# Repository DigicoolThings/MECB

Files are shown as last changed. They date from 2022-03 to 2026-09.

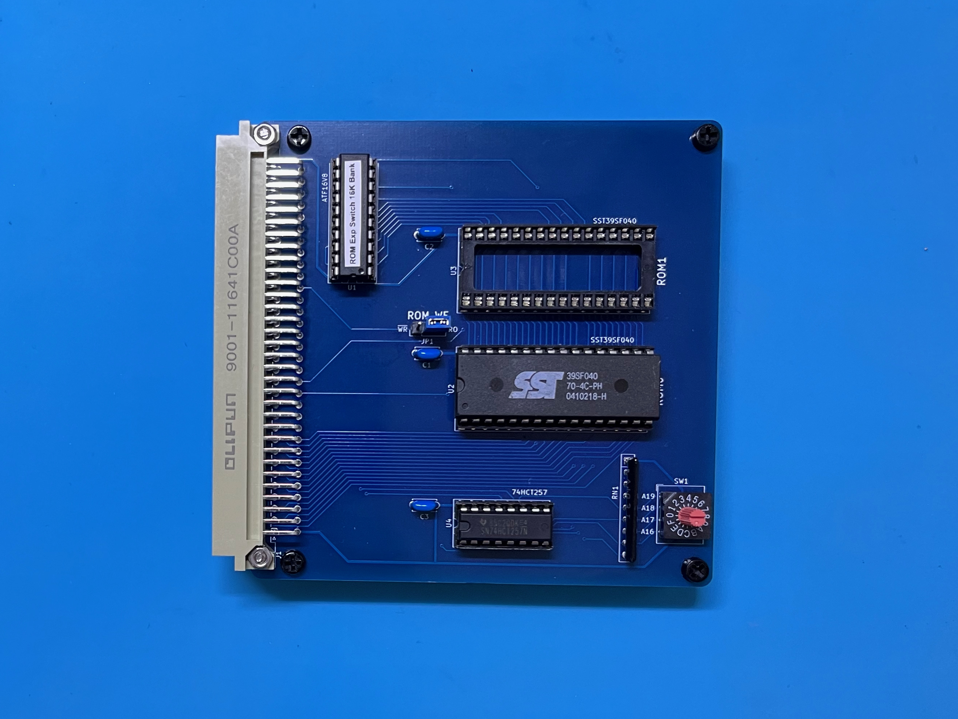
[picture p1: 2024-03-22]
MECB_1MB_ROM_Expansion/MECB_1MB_ROM_Expansion_Assembled.jpeg

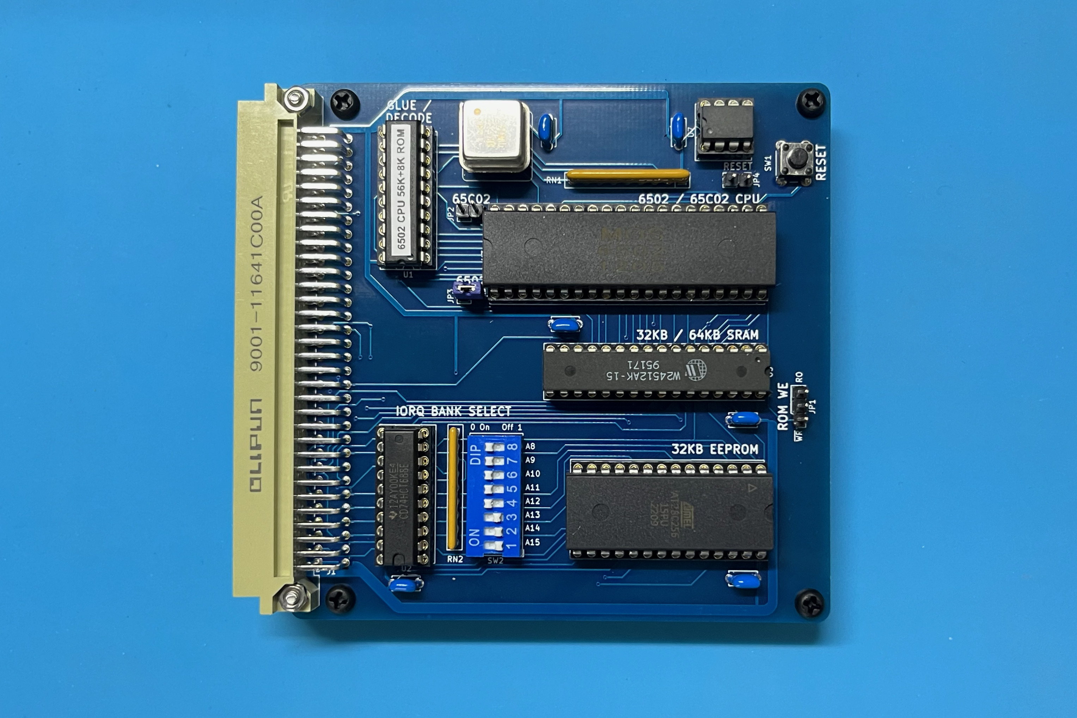
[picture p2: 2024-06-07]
MECB_6502_CPU/MECB_6502_CPU_Assembled_v1.0.jpeg

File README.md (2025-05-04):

# Minimalist Europe Card Bus (MECB)

Europe Card Bus (ECB) is a Retro CPU Bus standard from the late 1970’s / early 1980’s.

The “Minimalist Europe Card Bus” (MECB), as I call it, is a Retro 8-bit CPU Bus based PCB design standard that I decided to define & document. The purpose of which is to provide a modular platform for me to re-experience the fun of experimenting with the different 8-bit CPU’s, and the various video and peripheral devices, that I grew up with in the late 1970’s and early 1980’s.

My goal is that of a robust and modular design platform which would allow me to create interchangeable boards, based on time proven reliable bus connectors and modern low-cost prototype PCB manufacturing.

i.e. A robust, flexible, and low cost way for me to re-create some of the early microprocessor circuits, that I’d originally built using Wire-Wrap methods back in the day.

As evident from the name, the Bus itself is based on a Minimalist implementation of the original Europe Card Bus (ECB) standard.

The included 'MECB_Template_16V8' and 'MECB_Template_22V10' folders contains KiCAD v9 Templates to enable fast-tracking new MECB board designs. 
This templates also include the standardised PLD (either 16V8 or 22V10), for Address Decoding, and is as illustrated in the Standardised Board Mechanical Specifications diagram below.

To utilise either Template, simply copy the entire Template folder and contents into your KiCAD v9 'KICAD_USER_TEMPLATE_DIR' path folder (as defined under: Preferences -> Configure Paths...).

More information on the Minimalist Europe Card Bus (MECB) can be found here: https://digicoolthings.com/minimalist-europe-card-bus-mecb

## MECB Board Mechanical (MECB_BoardMechanical.pdf)
MECB_BoardMechanical

## MECB Bus Pinout (MECB_Bus_Pinout.png)
MECB_Bus_Pinout

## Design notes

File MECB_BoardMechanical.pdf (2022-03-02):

# Minimalist Europe Card Bus (MECB)

## Standardised Board - Mechanical Specifications

### Design Parameters

- Satisfy the 100mm square maximum board size, for low-cost prototype PCB manufacturing.
- Utilise the lower cost 64-pin (Row A&C) DIN 41612 type C connectors, for cost saving.
- Ensure the DIN 41612 connector(s) can be easily centred across the board width, grid aligned.
- Provide two standardised corner holes, on the edge opposing the right-angle DIN connector, to allow for attachment of card handles (to ease board insertion & extraction), or for board mounting – refer next point.
- Provide an additional two standardised corner mounting holes on the edge with the right-angle DIN connector, to provide a full set of four corner holes (to allow for stand-alone board mounting).
- Standardise PCB corner rounding, for sharp corner removal consistency across all boards & visual tidiness.

### Design Notes

1. PCB layout is designed utilising 0.127mm (5.0 mils) grid setting.
2. Board size is 99.822mm, which represents the greatest even multiple of 0.127mm (i.e. multiple of 0.254mm -10.0 mils), that will fit within the desired maximum 100mm board dimension.
3. Standard M3 sized mounting holes were chosen. An additional two mid-edge located mounting holes are specified for the Backplane board only (to provide additional mechanical support).
4. For reference, DIN 41612 connectors can utilise standard M2.5 mounting bolts (8mm length for the straight connectors, 10mm length for right angle connectors).
5. Implemented as a KiCAD Template, to assist with simplifying the creation of each new MECB board design.

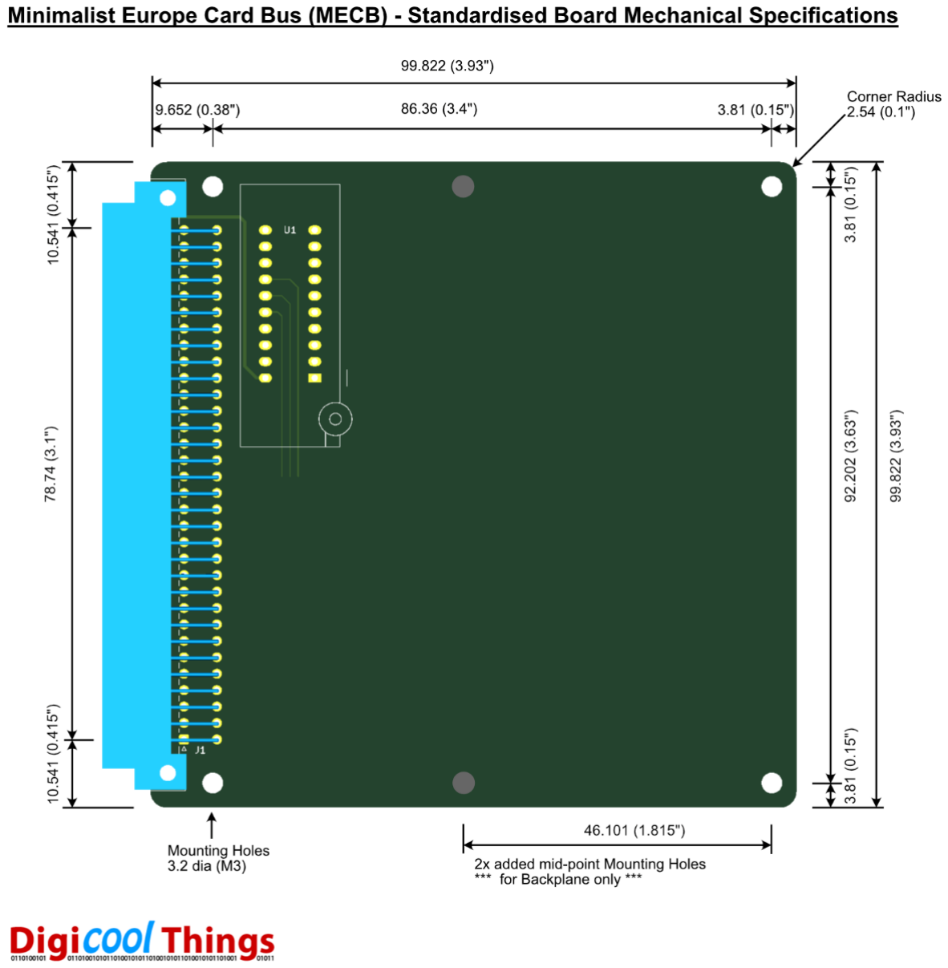
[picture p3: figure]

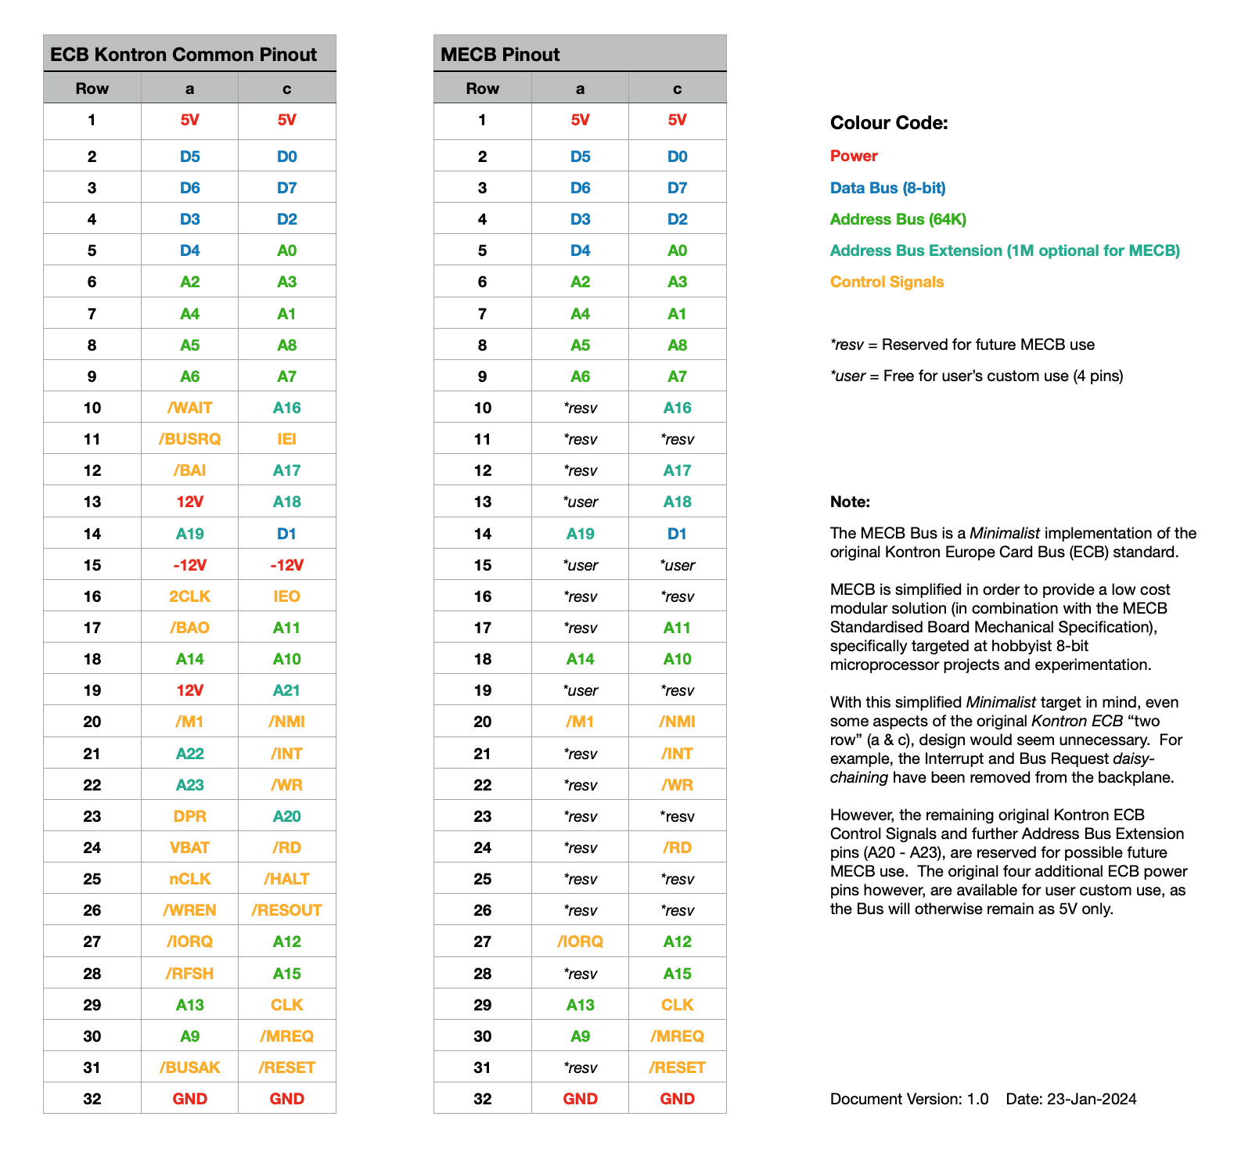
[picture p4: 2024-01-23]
MECB_Bus_Pinout.png

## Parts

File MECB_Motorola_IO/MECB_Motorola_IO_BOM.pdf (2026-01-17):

Item | Qty | Source
MECB Motorola I/O Card PCB | 1
DIN41612 Male R/A 364 Connector (J1) | 1 | Hardware Pack
M2.5 Bolt 10mm Thread Length | 2 | Hardware Pack
M2.5 Nut | 2 | Hardware Pack
12mm Nylon PCB Spacer | 4 | Hardware Pack
6mm Nylon Bolt | 8 | Hardware Pack
2 pin PCB Header (J2) | 1 | Hardware Pack
3 pin PCB Header (J7) | 1 | Hardware Pack
2 pin Jumper Cap | 1 | Hardware Pack
6 pin PCB Header Right-Angle (J6) | 1 | Hardware Pack
IDC Header 2x6 pin Straight (J4) | 1 | Hardware Pack
IDC Header 2x12 pin Right-Angle (J5) | 1 | Hardware Pack
3.5mm Phone Connector Audio Jack PCB Mount (J3) | 1 | Hardware Pack
4-way DIP Switch DIP8 (SW1) | 1 | Hardware Pack
ATF16V8 PLD DIP20 (U1) | 1 | Programmed ATF16V8 PLD Pack
Crystal Oscillator 4.9152Mhz DIP8 (X1) | 1 | Discrete Components Pack
0.1µf Capacitor 5mm (C1,C2,C3,C4,C5,C6) | 6 | Discrete Components Pack
47µf Radial Capacitor (C7) | 1 | Discrete Components Pack
3K3 Resistor 5.08mm (R1,R2) | 2 | Discrete Components Pack
VN10KN or 2N7000 N-Channel MOSFET TO92 (Q1) | 1 | Semiconductor Pack
74HCT393 Dual 4-bit binary ripple counter DIP14 (U2) | 1 | Semiconductor Pack
MC6850, MC68A50 or MC68B50 ACIA DIP24 (U3) | 1 | Semiconductor Pack
MC6840, MC68A40 or MC68B40 PTM DIP28 (U4) | 1 | Semiconductor Pack
SN76489AN Sound Generator DIP16 (U5) | 1 | Semiconductor Pack
MC6821, MC68A21 or MC68B21 PIA DIP40 (U6) | 1 | Semiconductor Pack
DIP40 IC Socket (for U6) | 1 | IC Socket Pack
DIP28 IC Socket (for U4) | 1 | IC Socket Pack
DIP24 IC Socket (for U3) | 1 | IC Socket Pack
DIP16 IC Socket (for U5) | 1 | IC Socket Pack
DIP14 IC Socket (for U2) | 1 | IC Socket Pack
DIP8 IC Socket (for X1) | 1 | IC Socket Pack

### MECB Motorola I/O - BOM

1

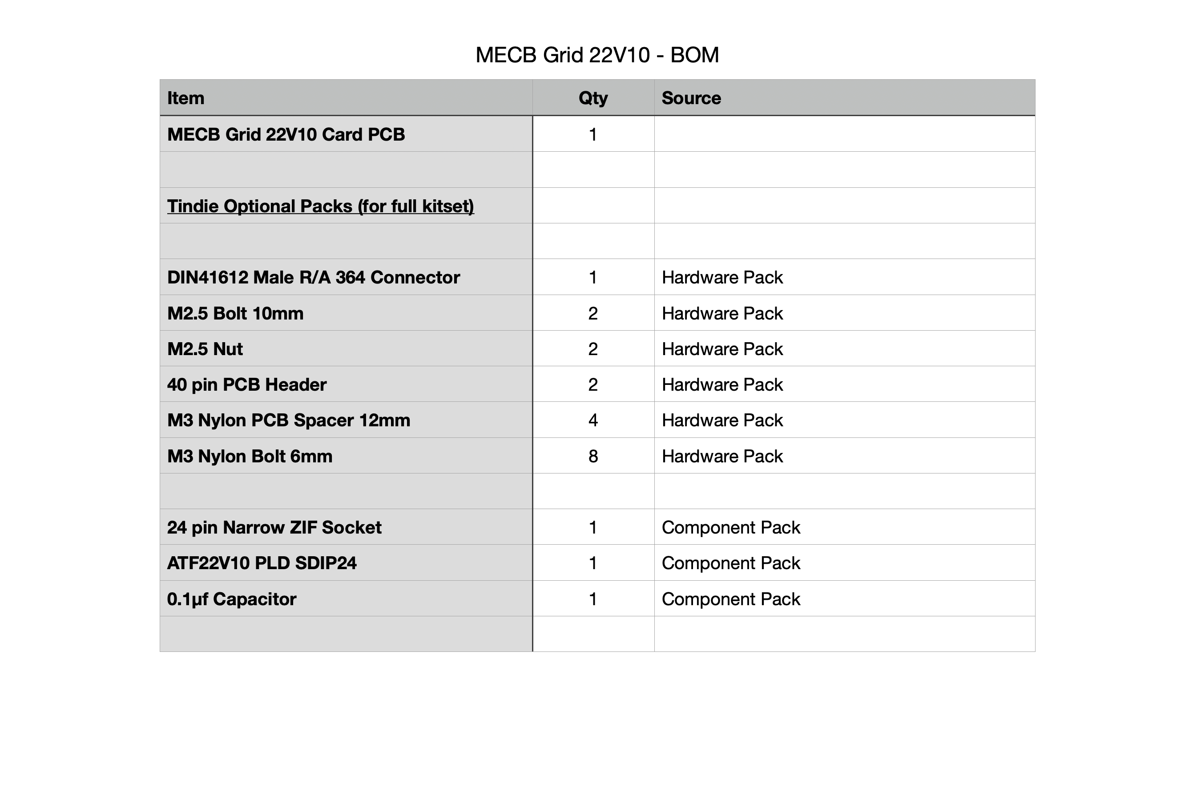
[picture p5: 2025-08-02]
MECB_Grid_22V10/MECB_Grid_22V10_BOM.png

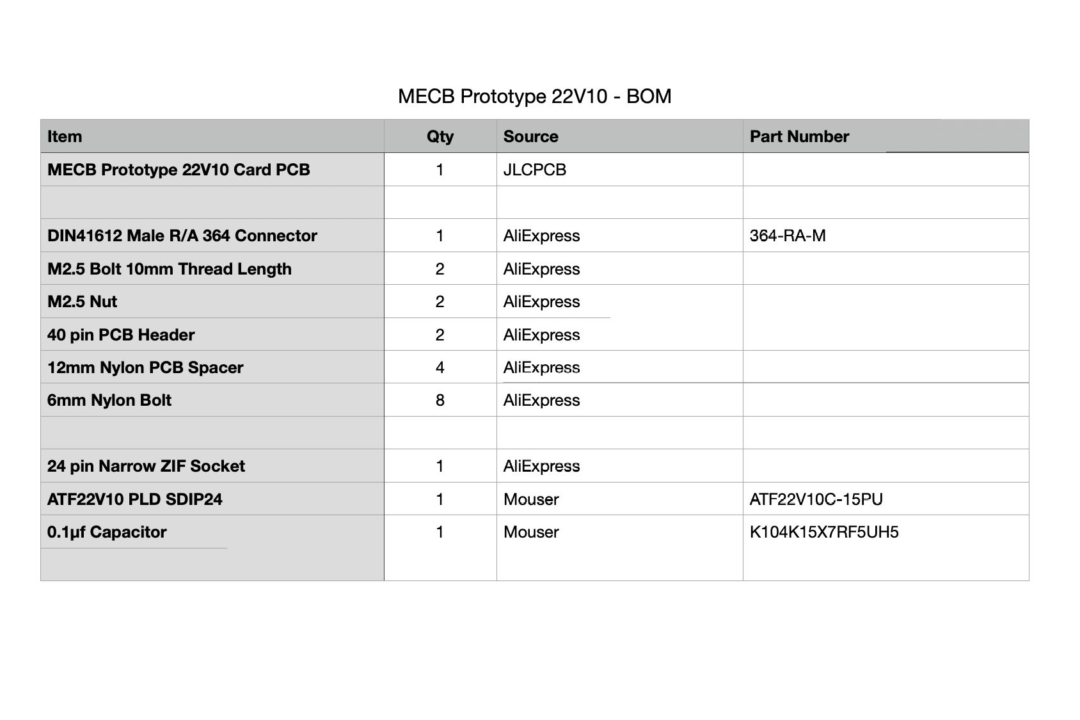
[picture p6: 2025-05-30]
MECB_Prototype_22V10/MECB_Prototype_22V10_BOM.png

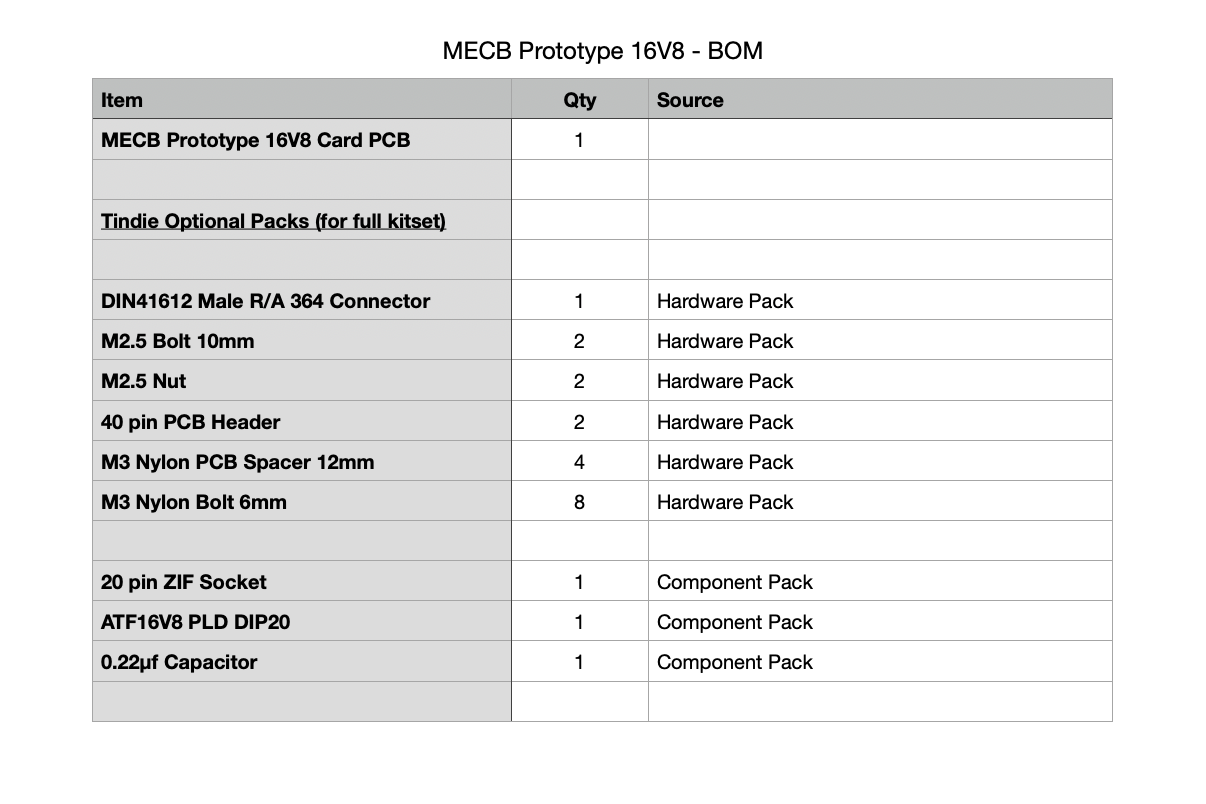
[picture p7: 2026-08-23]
MECB_Prototype_16V8/MECB_Prototype_16V8_BOM.png

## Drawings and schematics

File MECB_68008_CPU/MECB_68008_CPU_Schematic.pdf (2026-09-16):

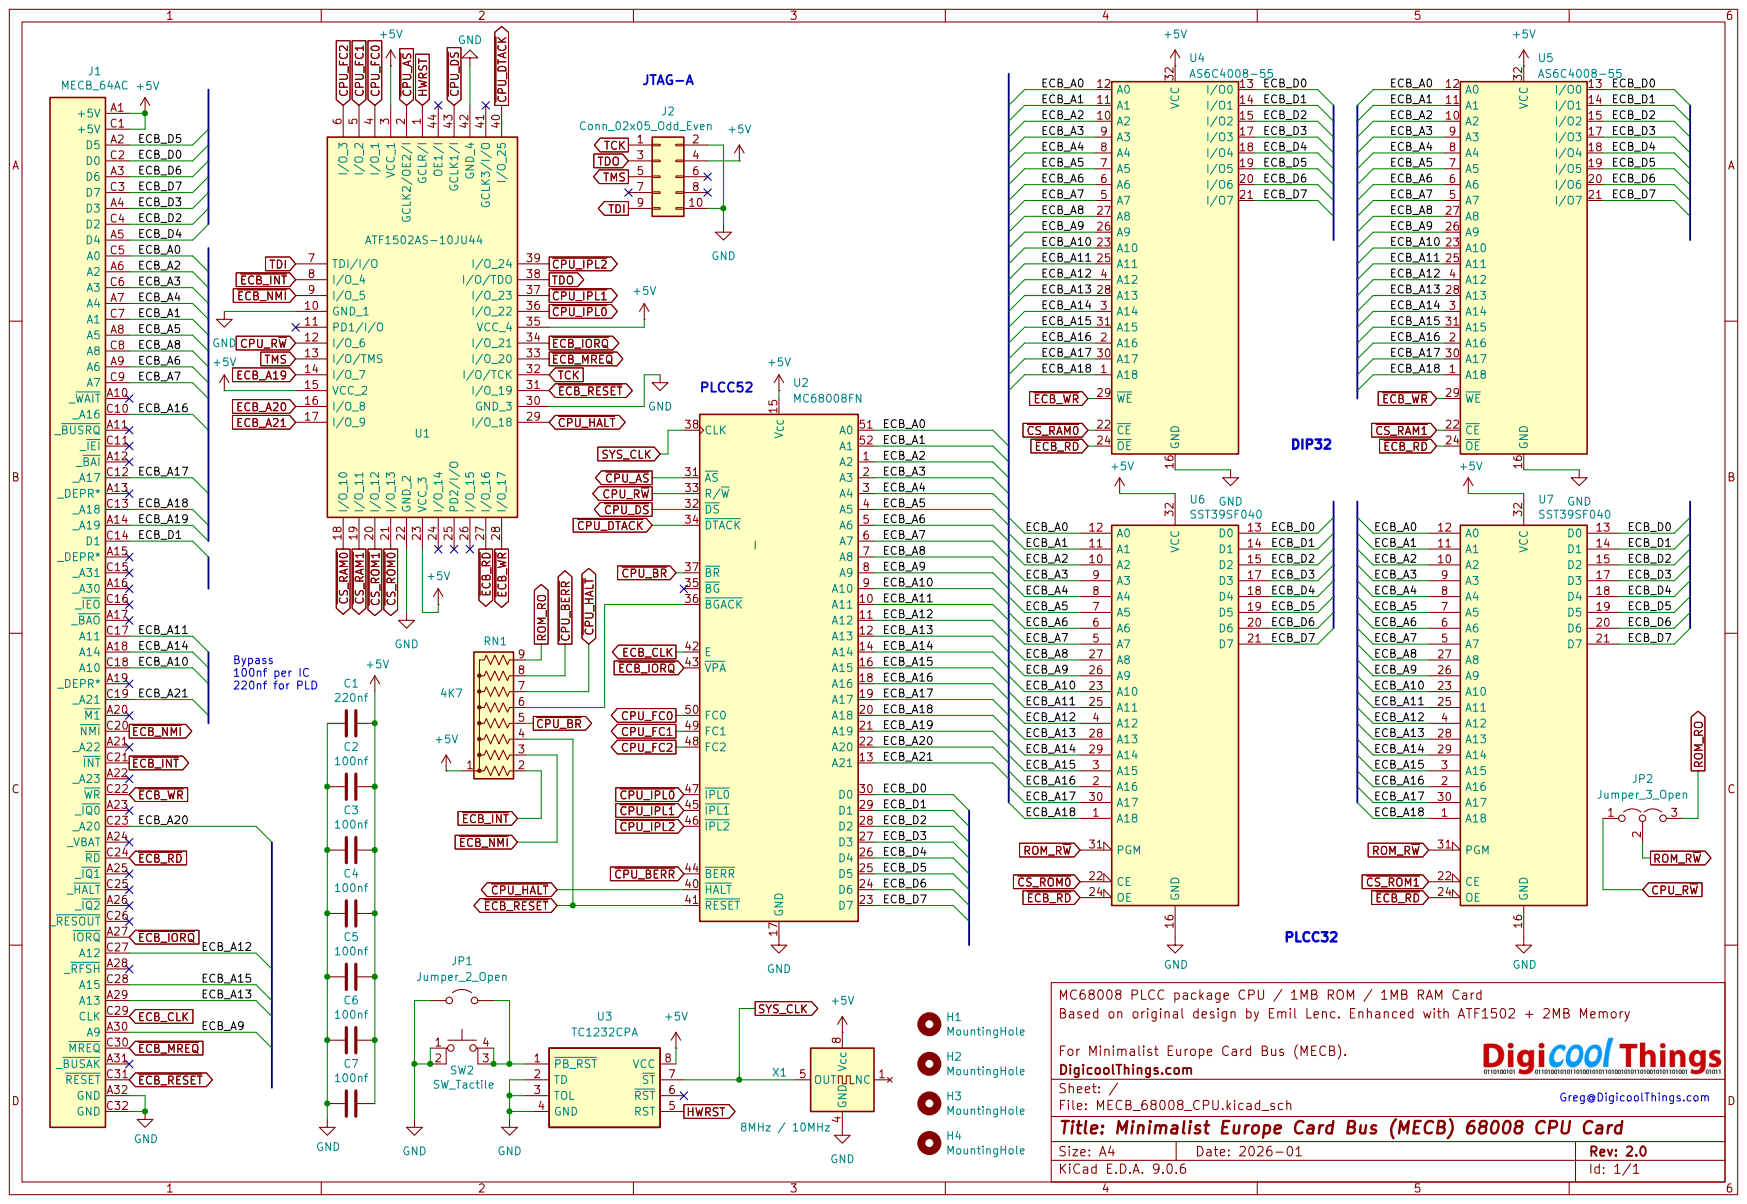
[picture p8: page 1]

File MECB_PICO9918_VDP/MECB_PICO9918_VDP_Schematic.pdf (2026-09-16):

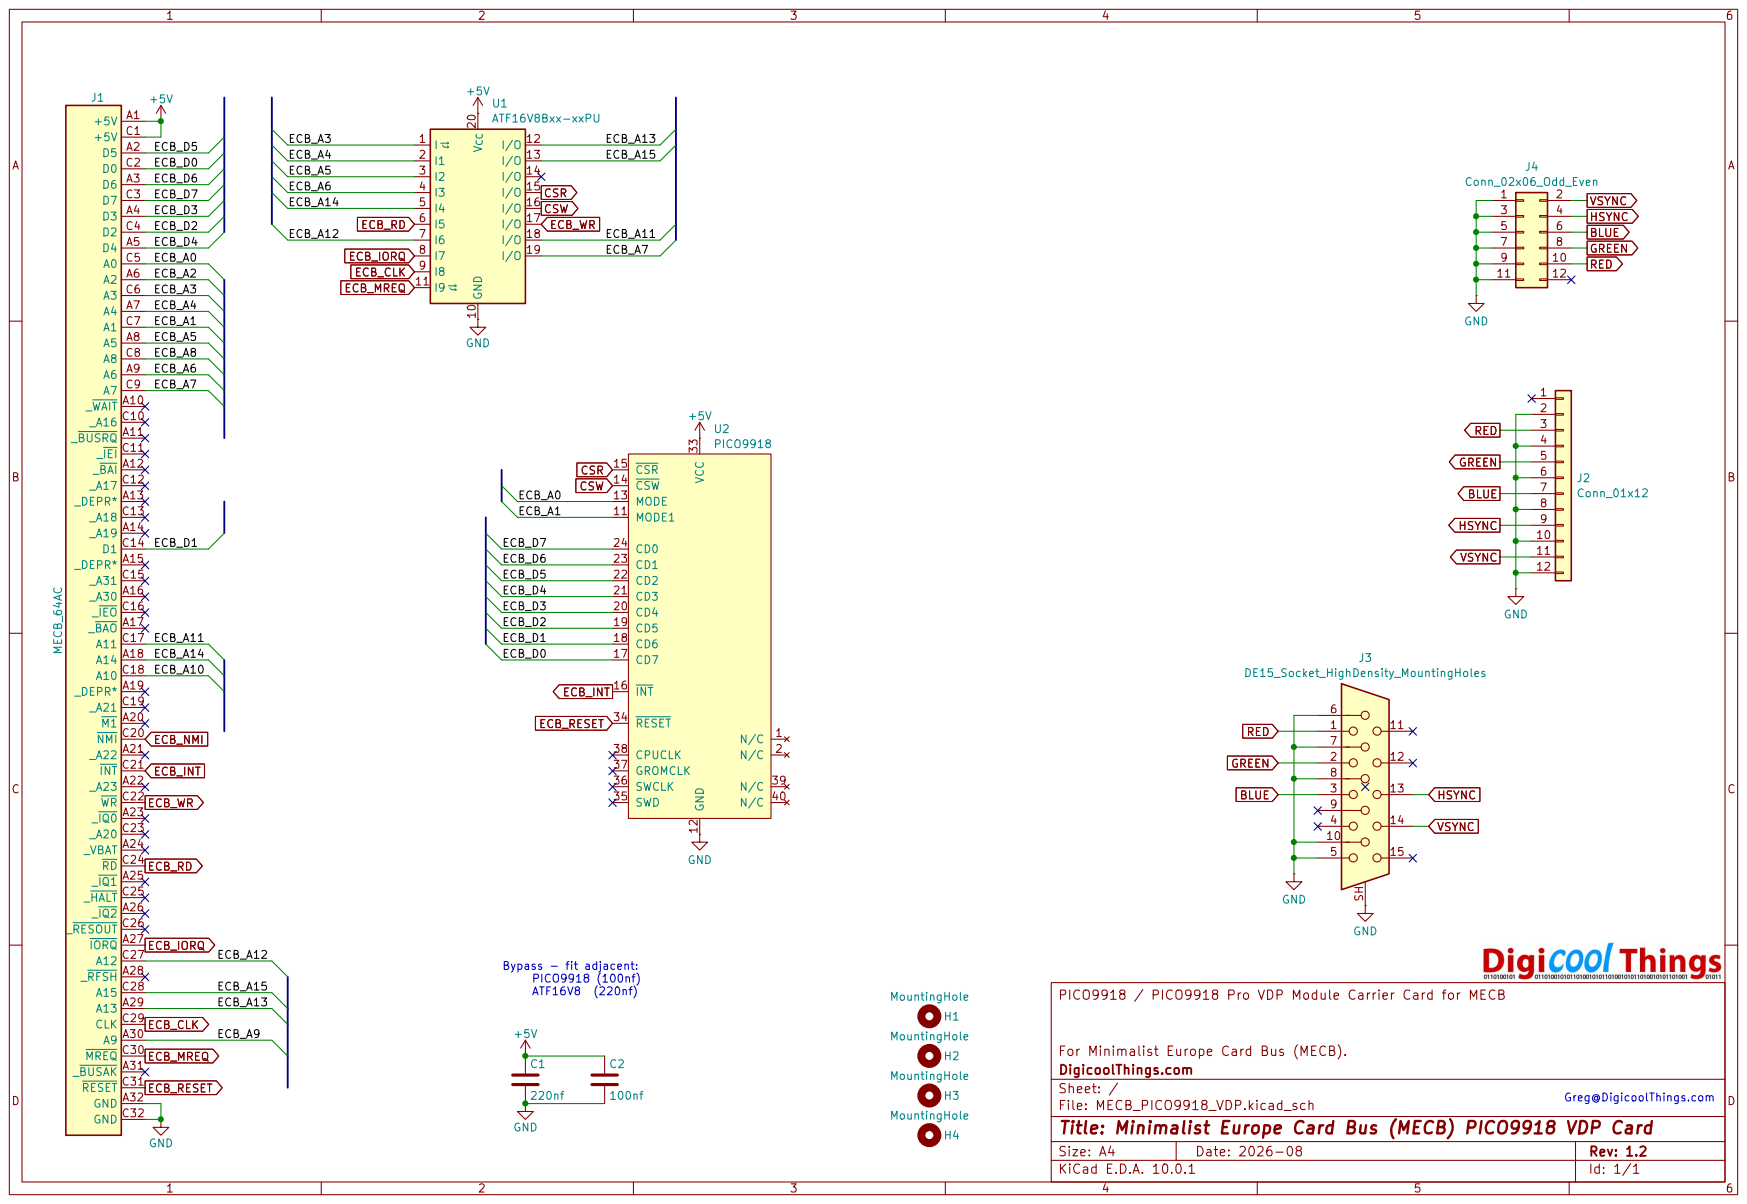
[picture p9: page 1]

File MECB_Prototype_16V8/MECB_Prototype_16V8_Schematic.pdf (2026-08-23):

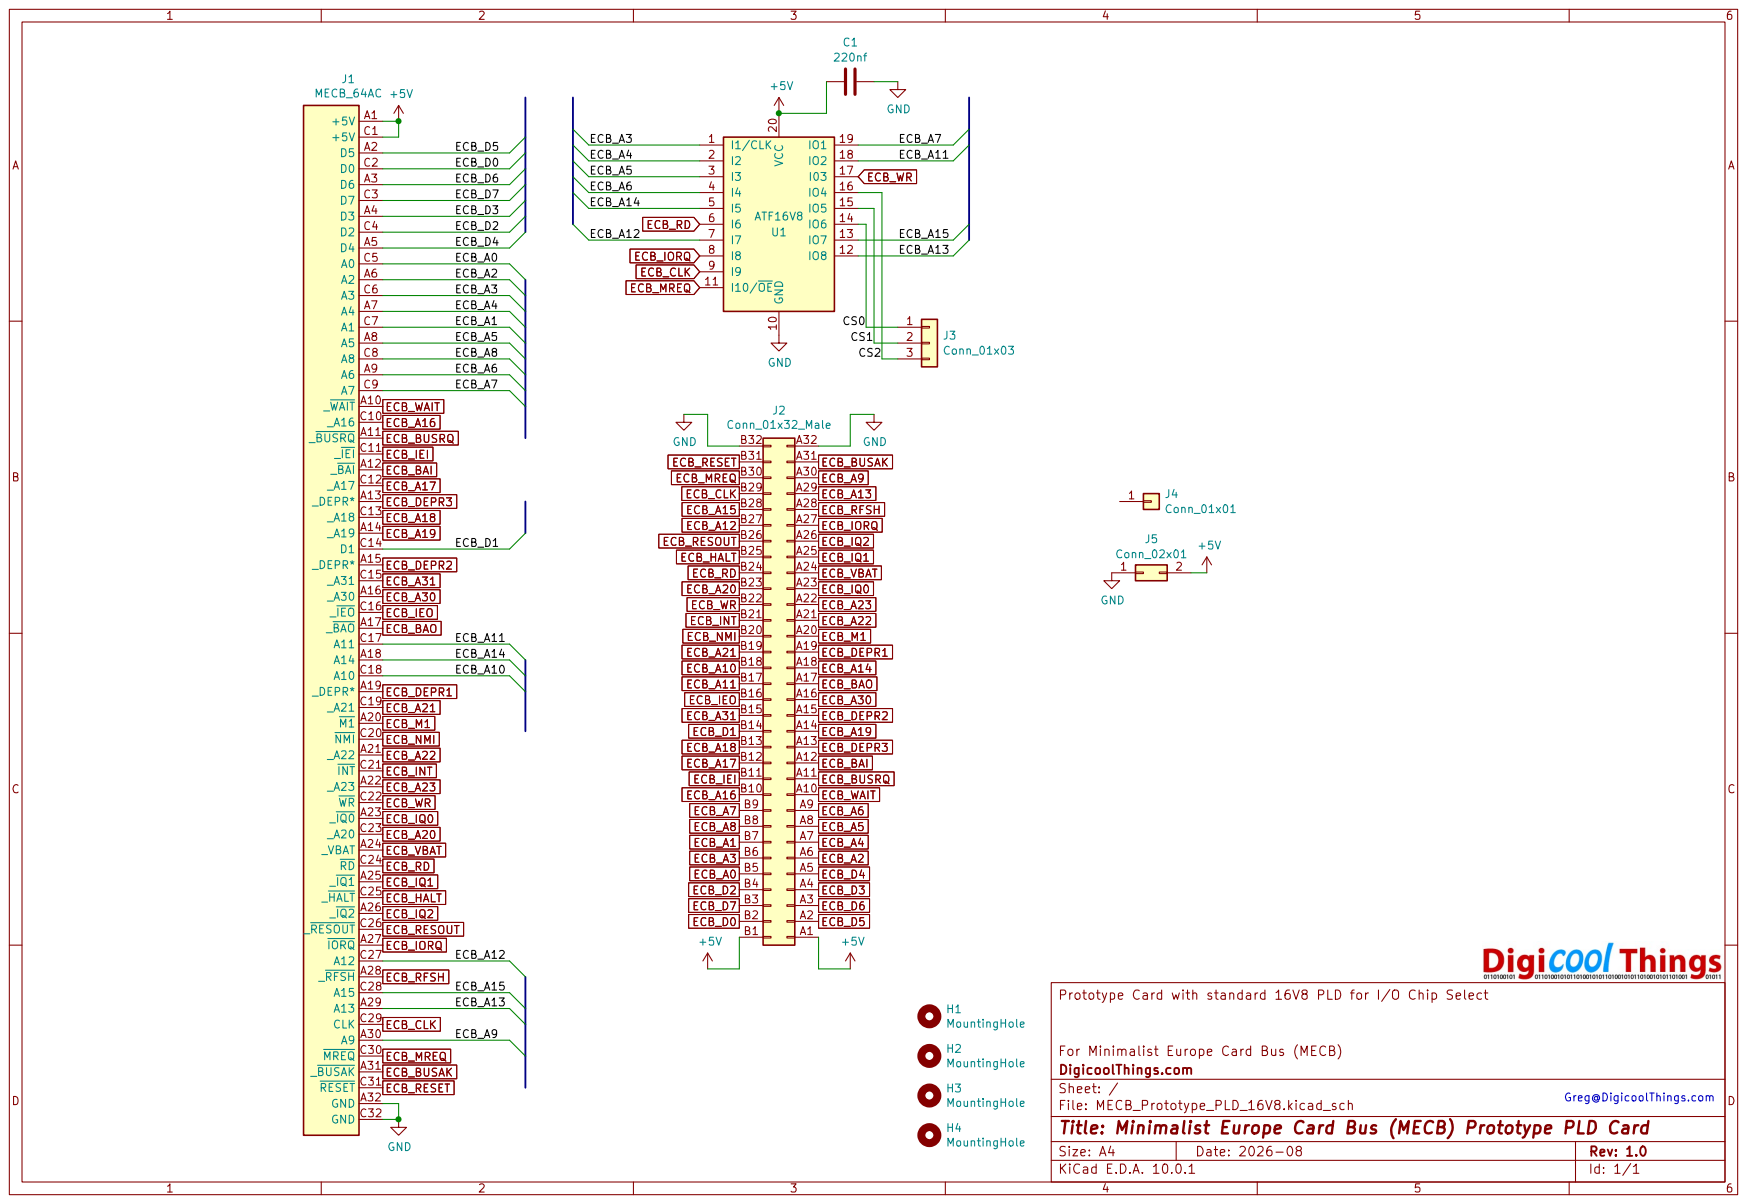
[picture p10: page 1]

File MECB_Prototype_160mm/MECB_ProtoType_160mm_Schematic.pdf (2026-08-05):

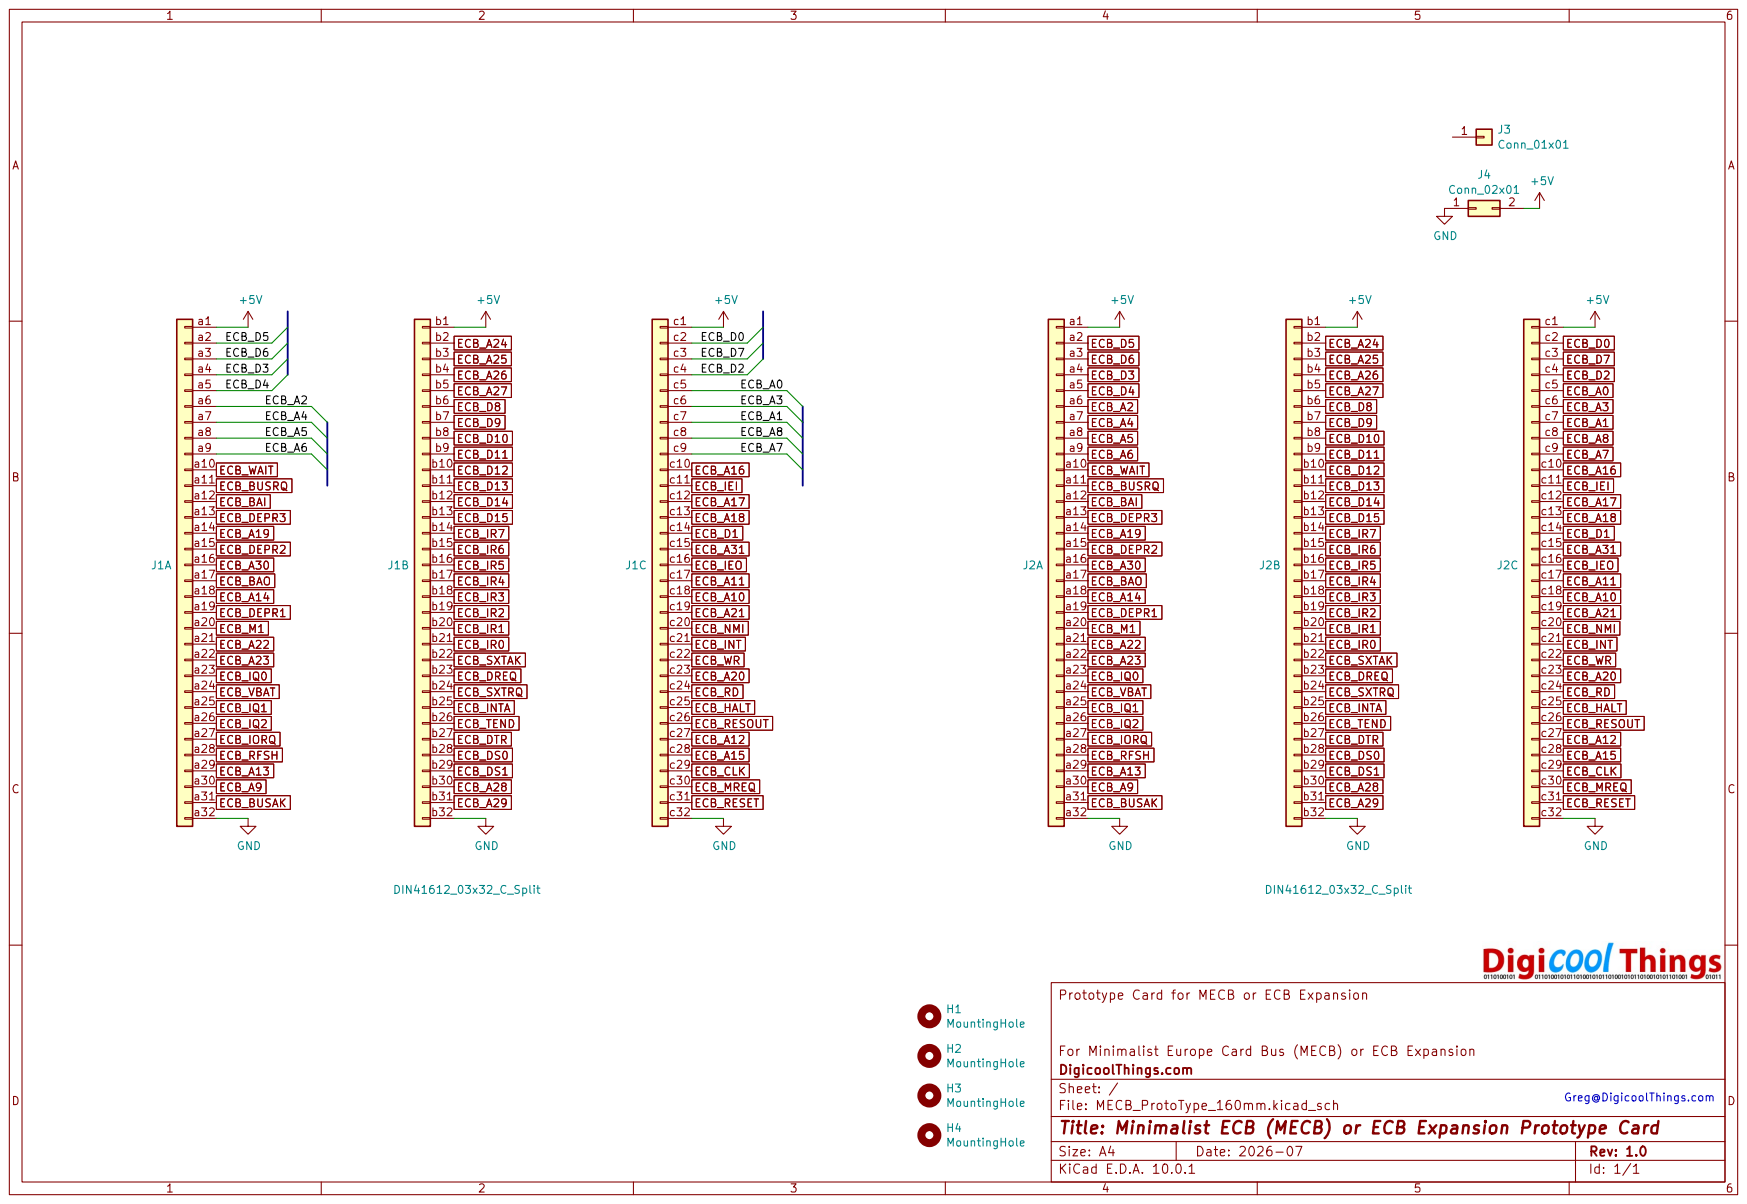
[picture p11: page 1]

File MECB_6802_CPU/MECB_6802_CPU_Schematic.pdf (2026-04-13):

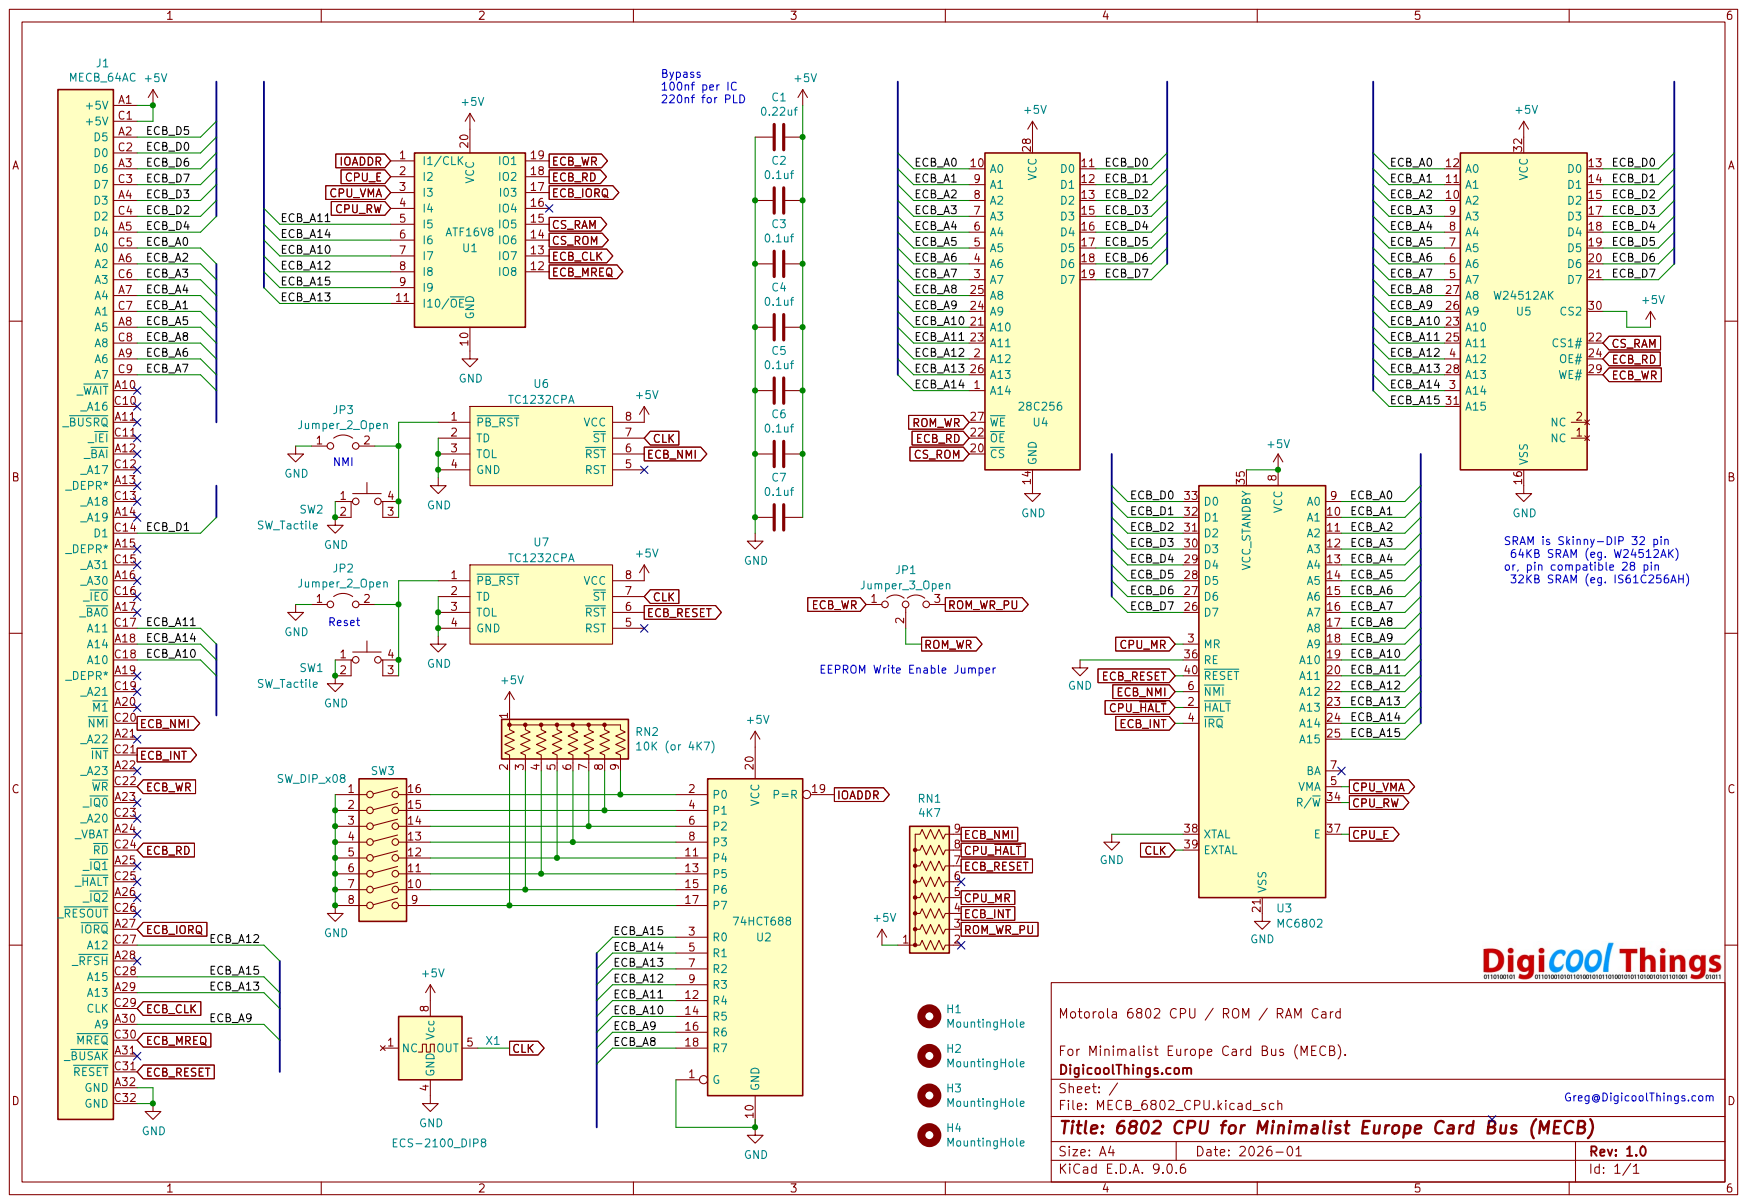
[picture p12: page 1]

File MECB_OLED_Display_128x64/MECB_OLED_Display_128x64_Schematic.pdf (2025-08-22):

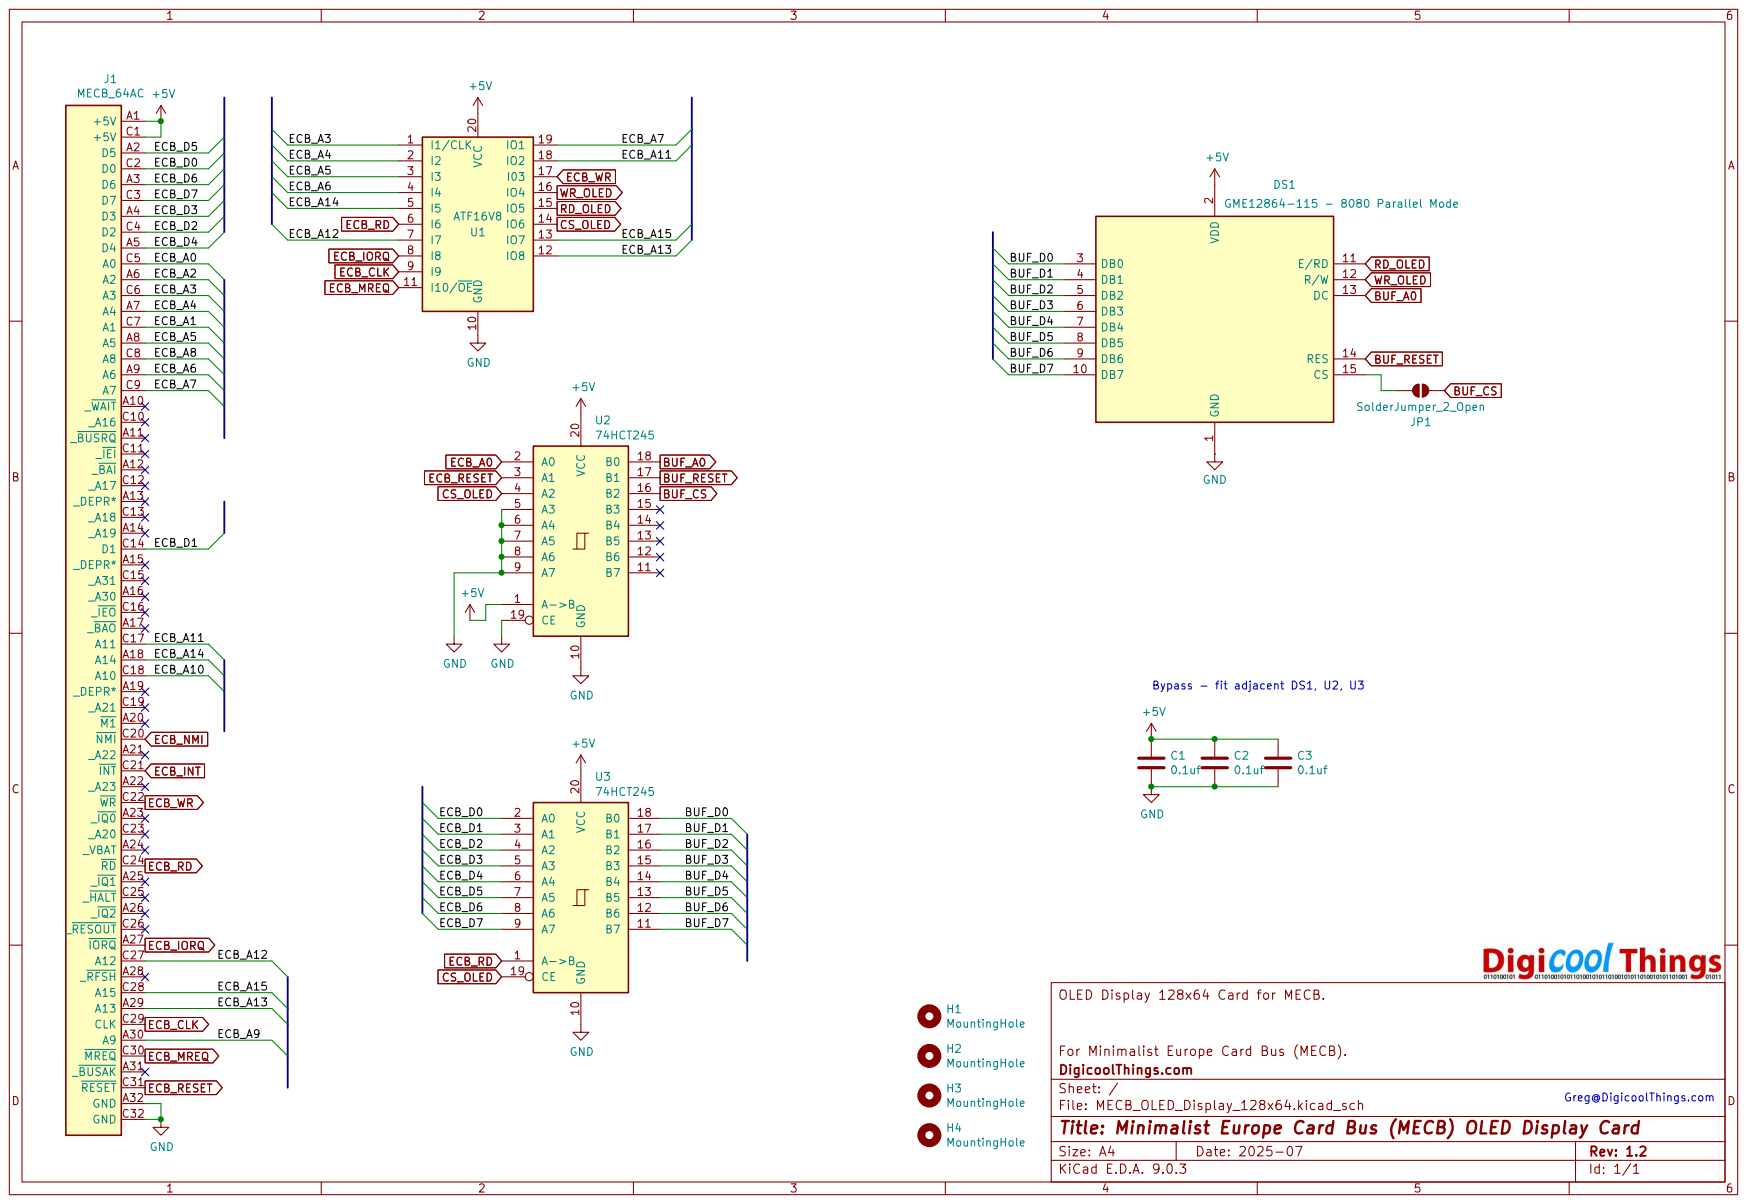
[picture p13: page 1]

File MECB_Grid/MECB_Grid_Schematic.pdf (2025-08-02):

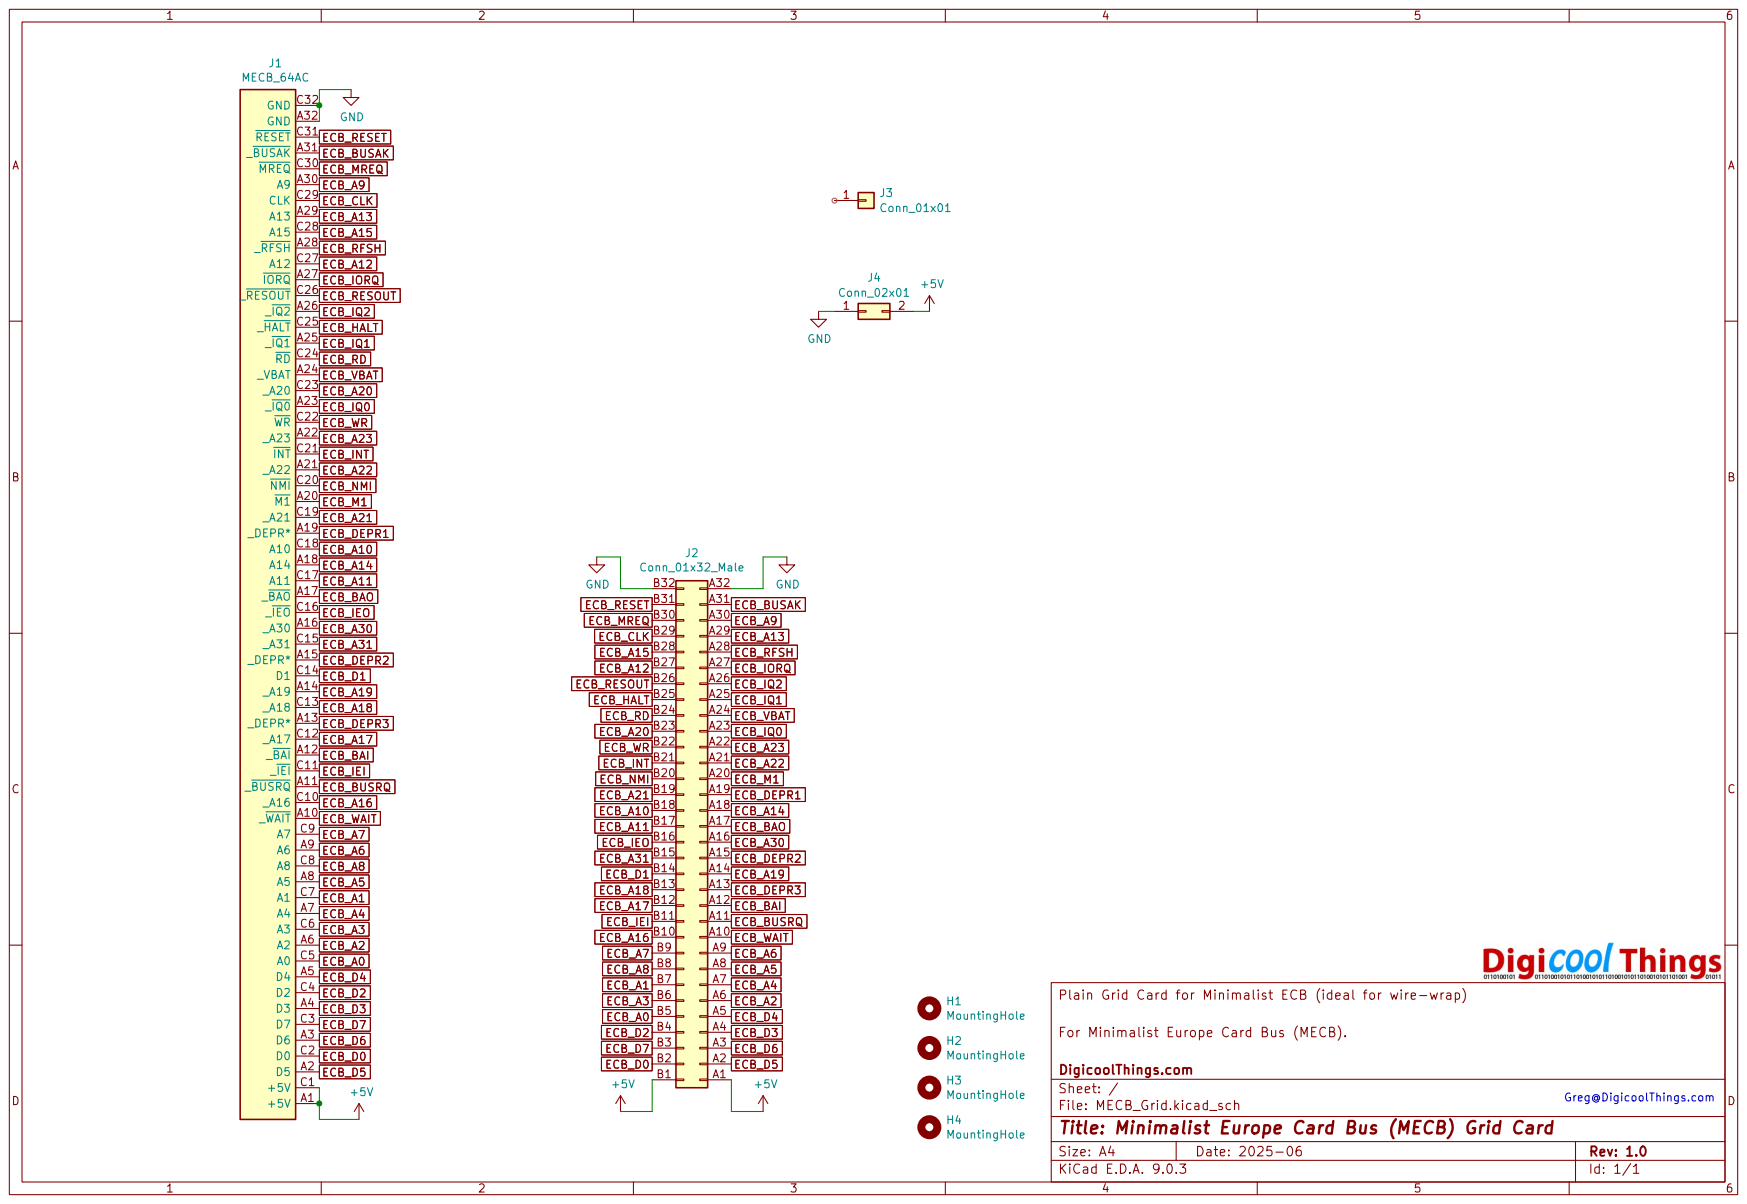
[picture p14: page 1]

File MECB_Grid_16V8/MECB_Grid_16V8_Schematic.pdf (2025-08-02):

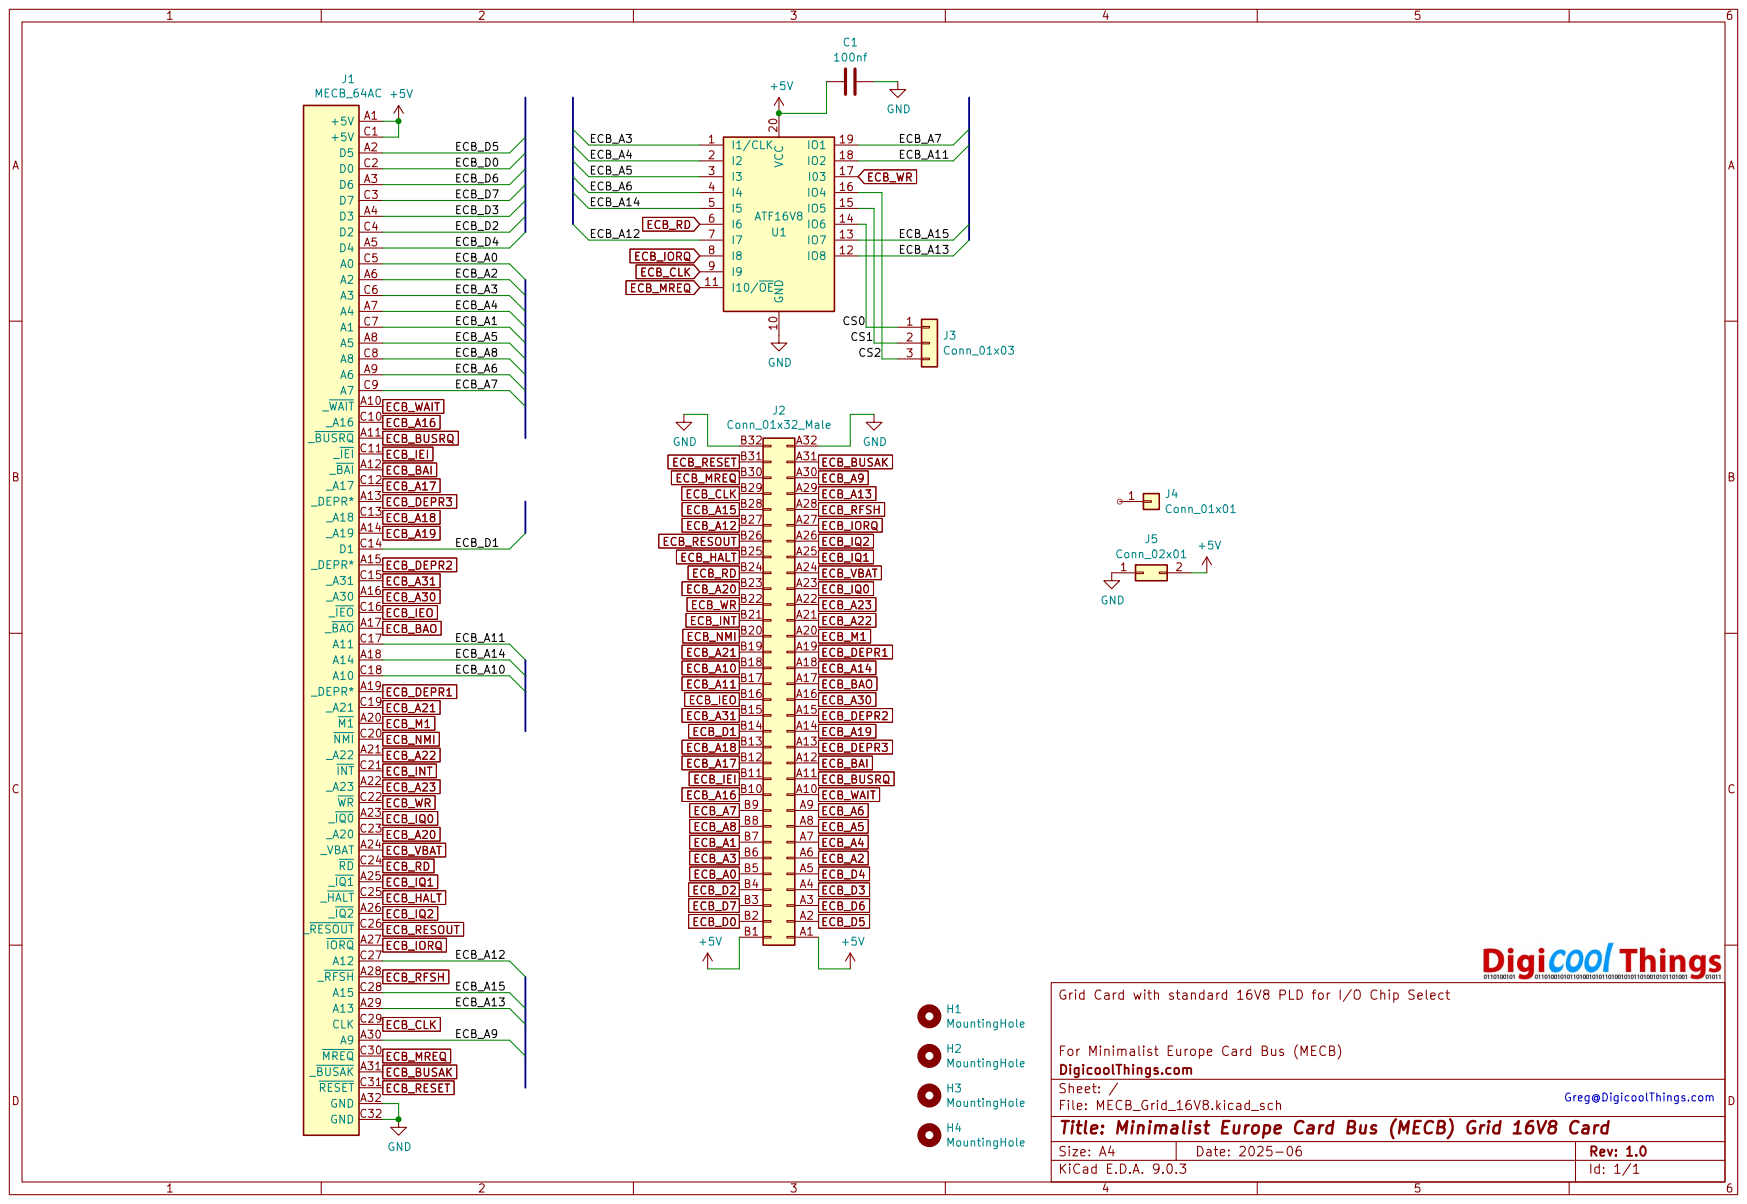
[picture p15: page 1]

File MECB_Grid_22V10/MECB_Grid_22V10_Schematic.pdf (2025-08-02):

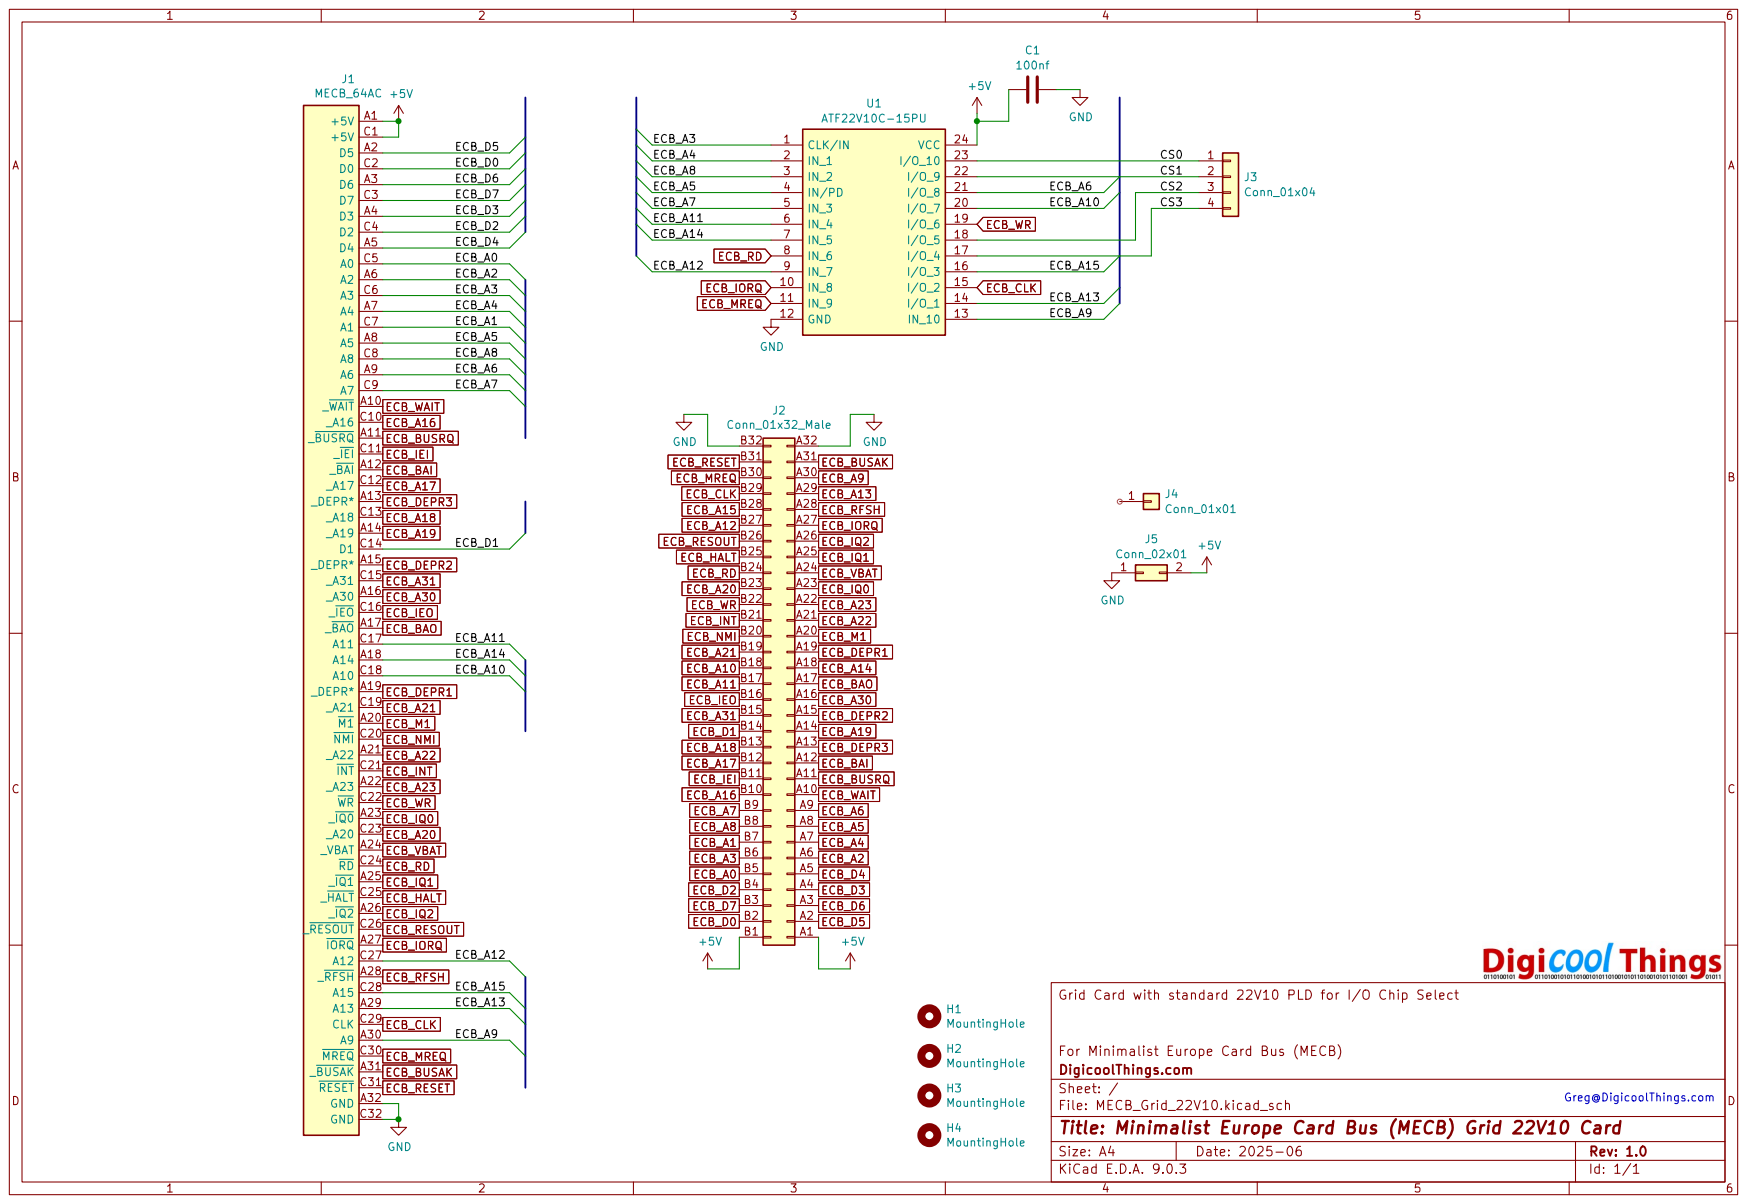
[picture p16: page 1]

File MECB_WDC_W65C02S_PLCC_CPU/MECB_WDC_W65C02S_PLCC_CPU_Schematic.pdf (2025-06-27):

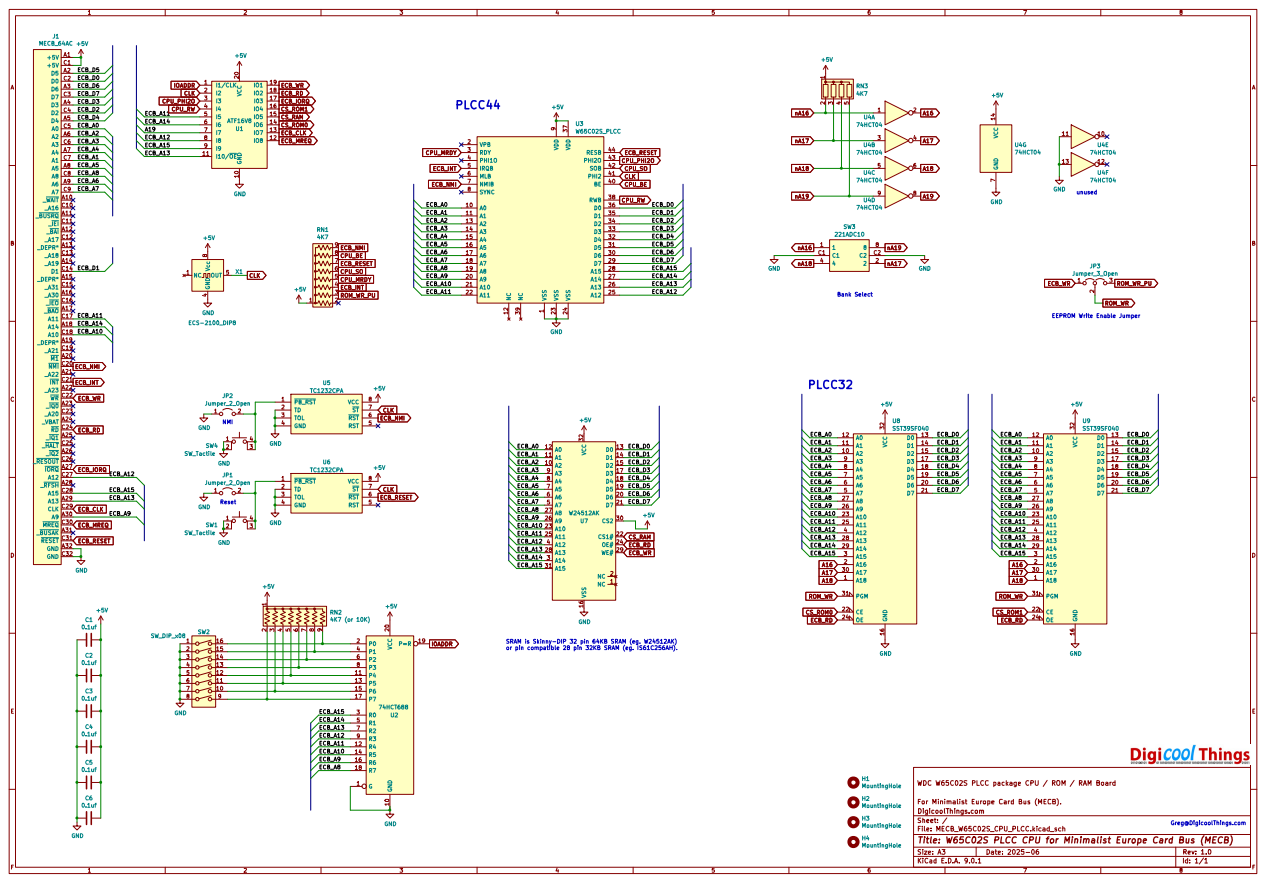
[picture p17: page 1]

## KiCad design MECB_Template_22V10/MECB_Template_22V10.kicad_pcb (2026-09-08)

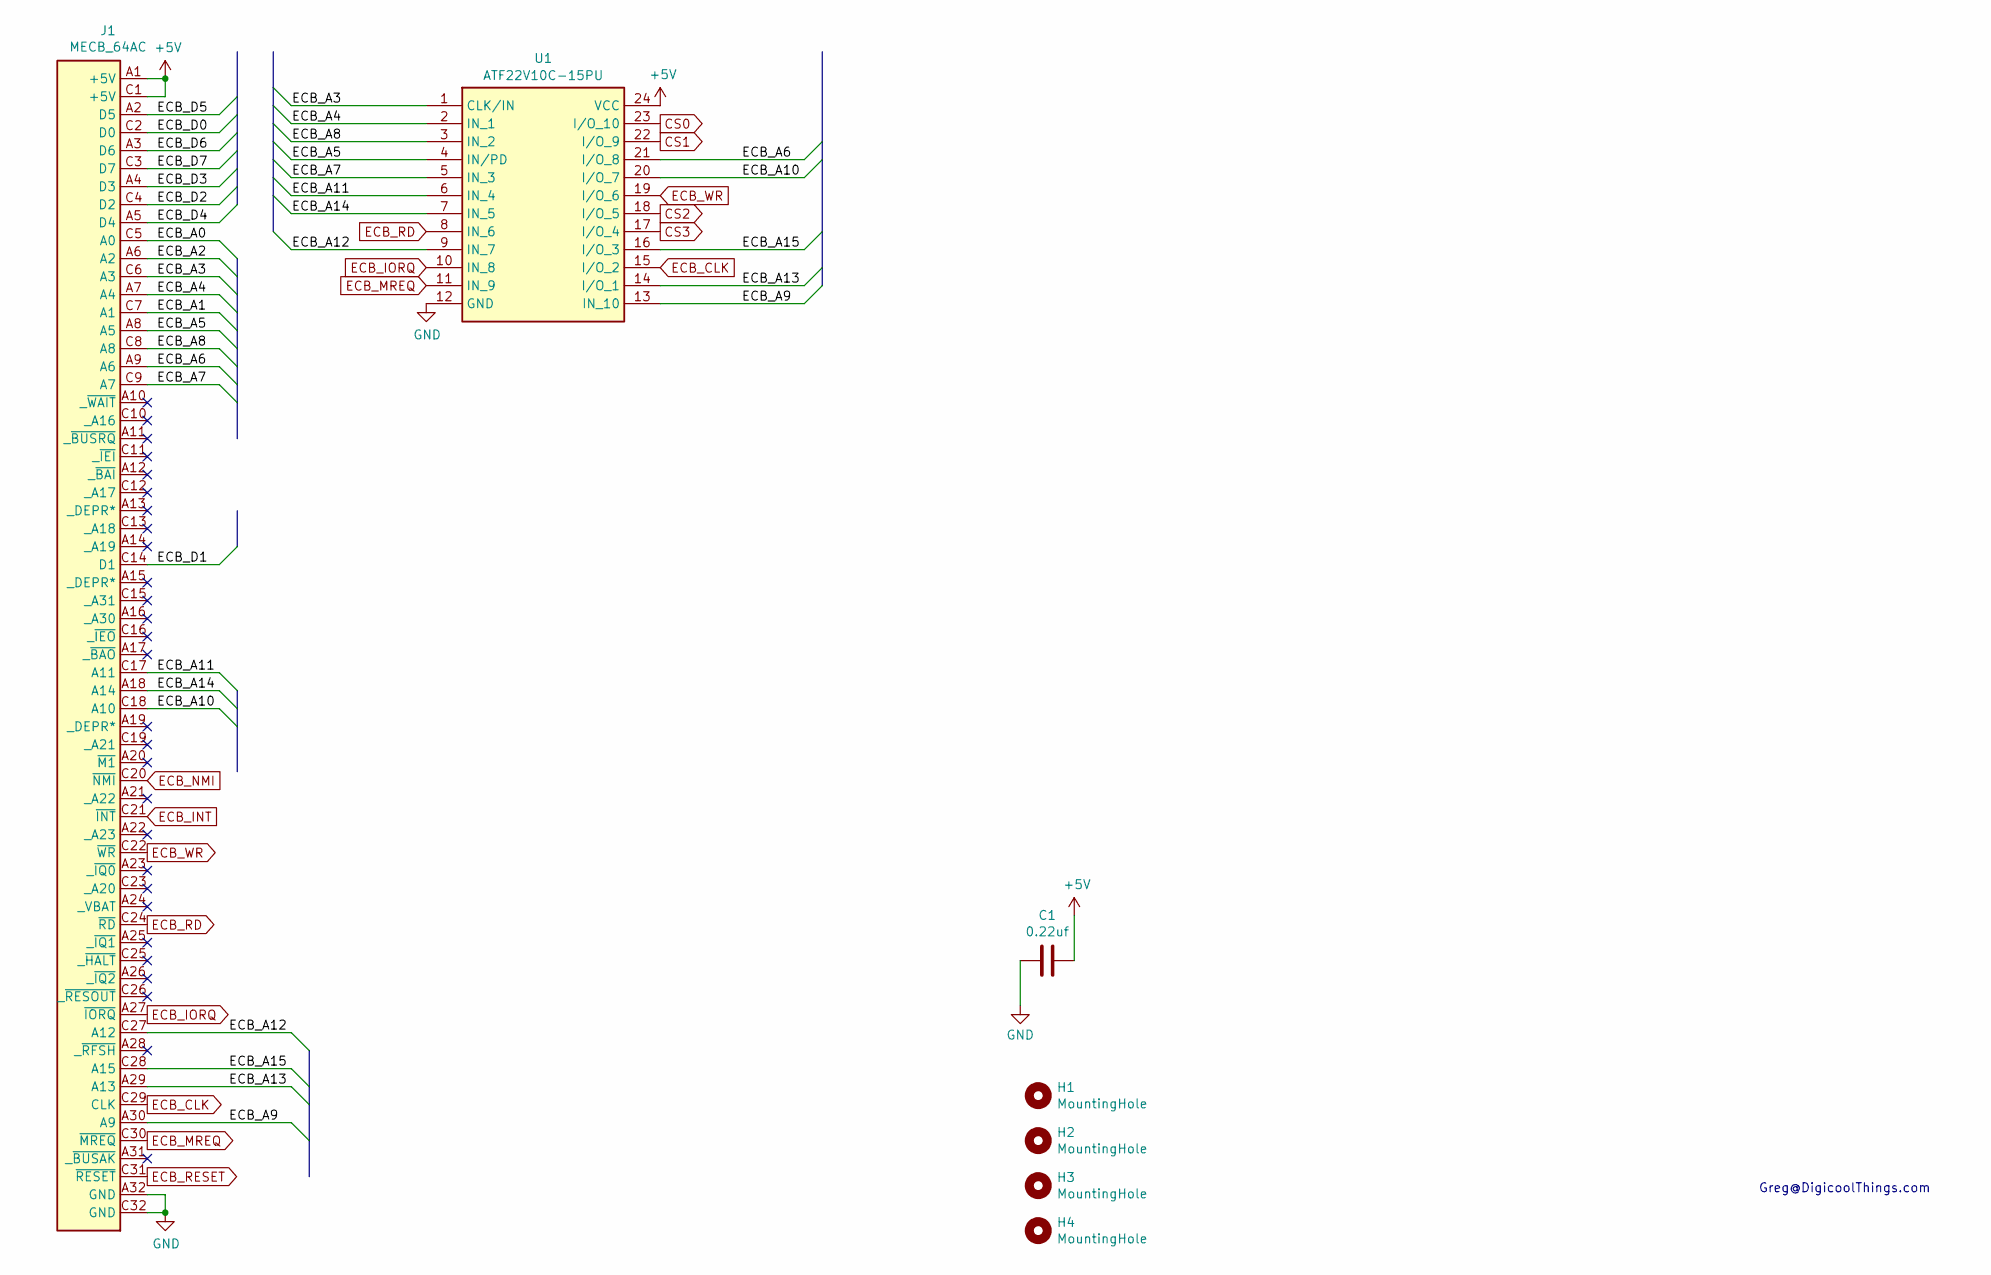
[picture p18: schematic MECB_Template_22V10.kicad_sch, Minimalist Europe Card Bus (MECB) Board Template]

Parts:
C1: 0.22uf; C_Disc_D5.0mm_W2.5mm_P5.00mm
H1, H2, H3, H4: MountingHole; MountingHole_3.2mm_M3
J1: MECB_64AC; DIN41612_C_2x32_C64AC_Male_Horizontal_THT
U1: ATF22V10C-15PU; DIP-24_W7.62mm_Socket_LongPads_ZIF_Friendly; Mouser Part Number 556-AF22V10C15PU

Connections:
+5V: C1.1, J1.A1 (+5V), J1.C1 (+5V), U1.24 (VCC)
/ECB_A0: J1.C5 (A0)
/ECB_A1: J1.C7 (A1)
/ECB_A2: J1.A6 (A2)
/ECB_A3: J1.C6 (A3), U1.1 (CLK/IN)
/ECB_A4: J1.A7 (A4), U1.2 (IN_1)
/ECB_A5: J1.A8 (A5), U1.4 (IN/PD)
/ECB_A6: J1.A9 (A6), U1.21 (I/O_8)
/ECB_A7: J1.C9 (A7), U1.5 (IN_3)
/ECB_A8: J1.C8 (A8), U1.3 (IN_2)
/ECB_A9: J1.A30 (A9), U1.13 (IN_10)
/ECB_A10: J1.C18 (A10), U1.20 (I/O_7)
/ECB_A11: J1.C17 (A11), U1.6 (IN_4)
/ECB_A12: J1.C27 (A12), U1.9 (IN_7)
/ECB_A13: J1.A29 (A13), U1.14 (I/O_1)
/ECB_A14: J1.A18 (A14), U1.7 (IN_5)
/ECB_A15: J1.C28 (A15), U1.16 (I/O_3)
/ECB_D0: J1.C2 (D0)
/ECB_D1: J1.C14 (D1)
/ECB_D2: J1.C4 (D2)
/ECB_D3: J1.A4 (D3)
/ECB_D4: J1.A5 (D4)
/ECB_D5: J1.A2 (D5)
/ECB_D6: J1.A3 (D6)
/ECB_D7: J1.C3 (D7)
CS0: U1.23 (I/O_10)
CS1: U1.22 (I/O_9)
CS2: U1.18 (I/O_5)
CS3: U1.17 (I/O_4)
ECB_CLK: J1.C29 (CLK), U1.15 (I/O_2)
ECB_INT: J1.C21 (~INT)
ECB_IORQ: J1.A27 (~IORQ), U1.10 (IN_8)
ECB_MREQ: J1.C30 (~MREQ), U1.11 (IN_9)
ECB_NMI: J1.C20 (~NMI)
ECB_RD: J1.C24 (~RD), U1.8 (IN_6)
ECB_RESET: J1.C31 (~RESET)
ECB_WR: J1.C22 (~WR), U1.19 (I/O_6)
GND: C1.2, J1.A32 (GND), J1.C32 (GND), U1.12 (GND)

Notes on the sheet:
Greg@DigicoolThings.com

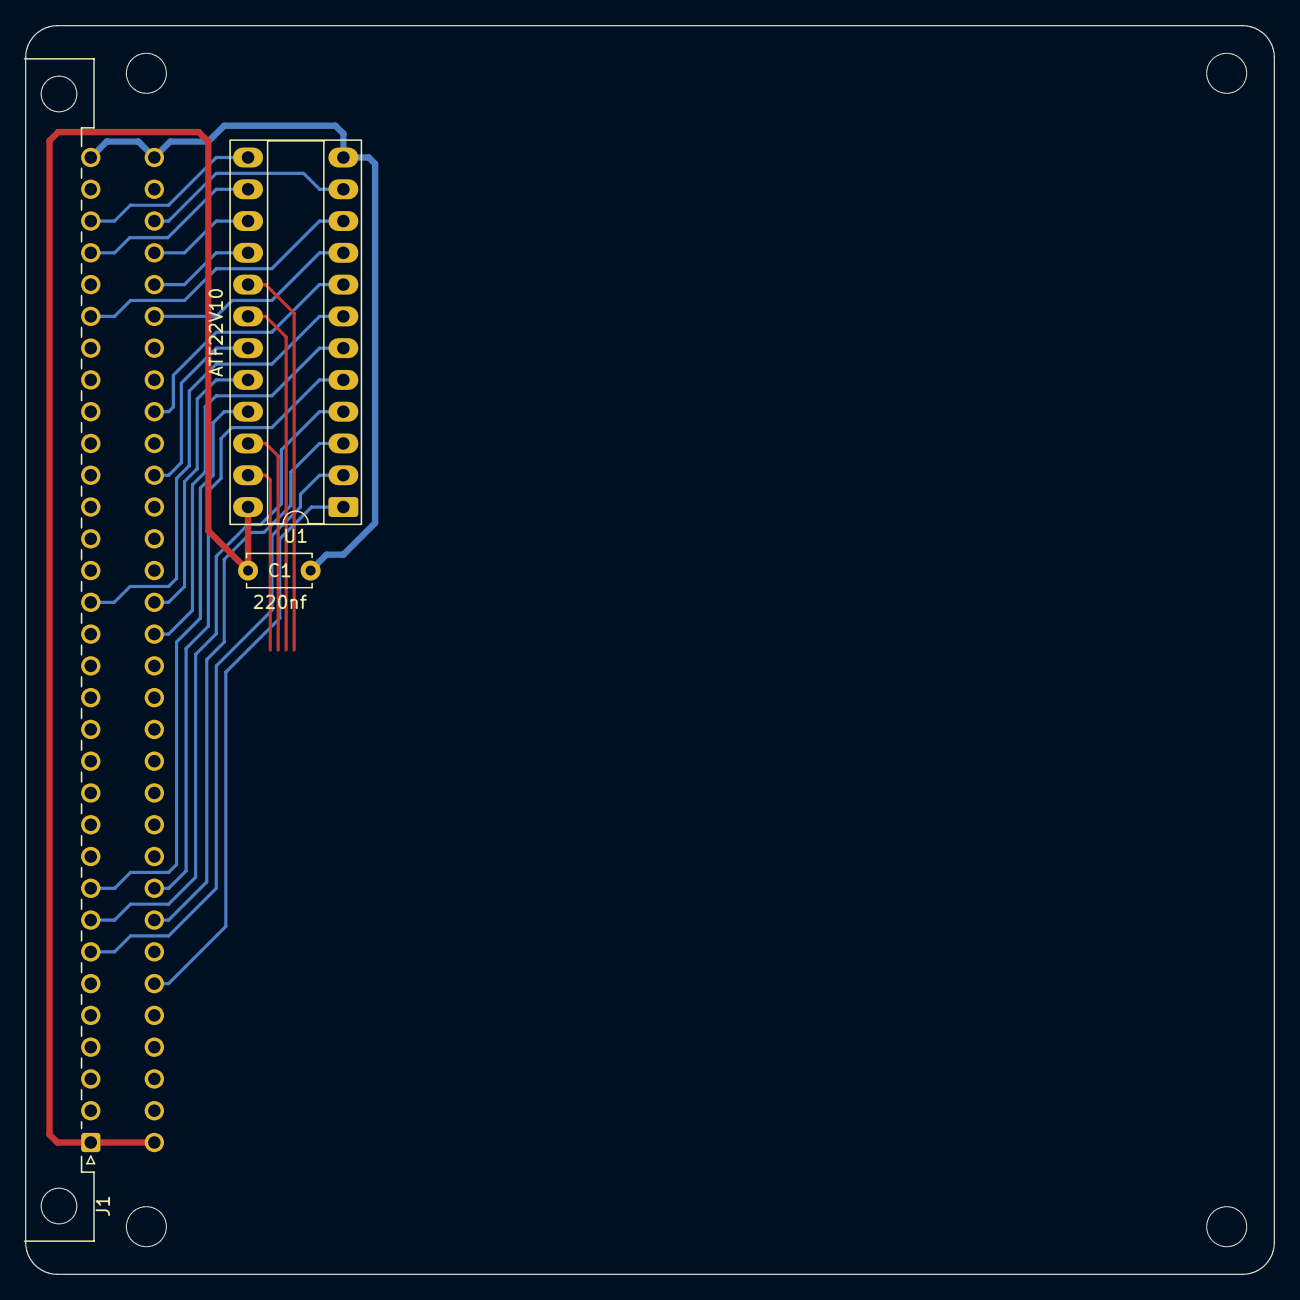
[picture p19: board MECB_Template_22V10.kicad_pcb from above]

Board: 2 copper layers, 99.8 x 99.8 mm, 7 parts (0 on the bottom side), 20 nets.

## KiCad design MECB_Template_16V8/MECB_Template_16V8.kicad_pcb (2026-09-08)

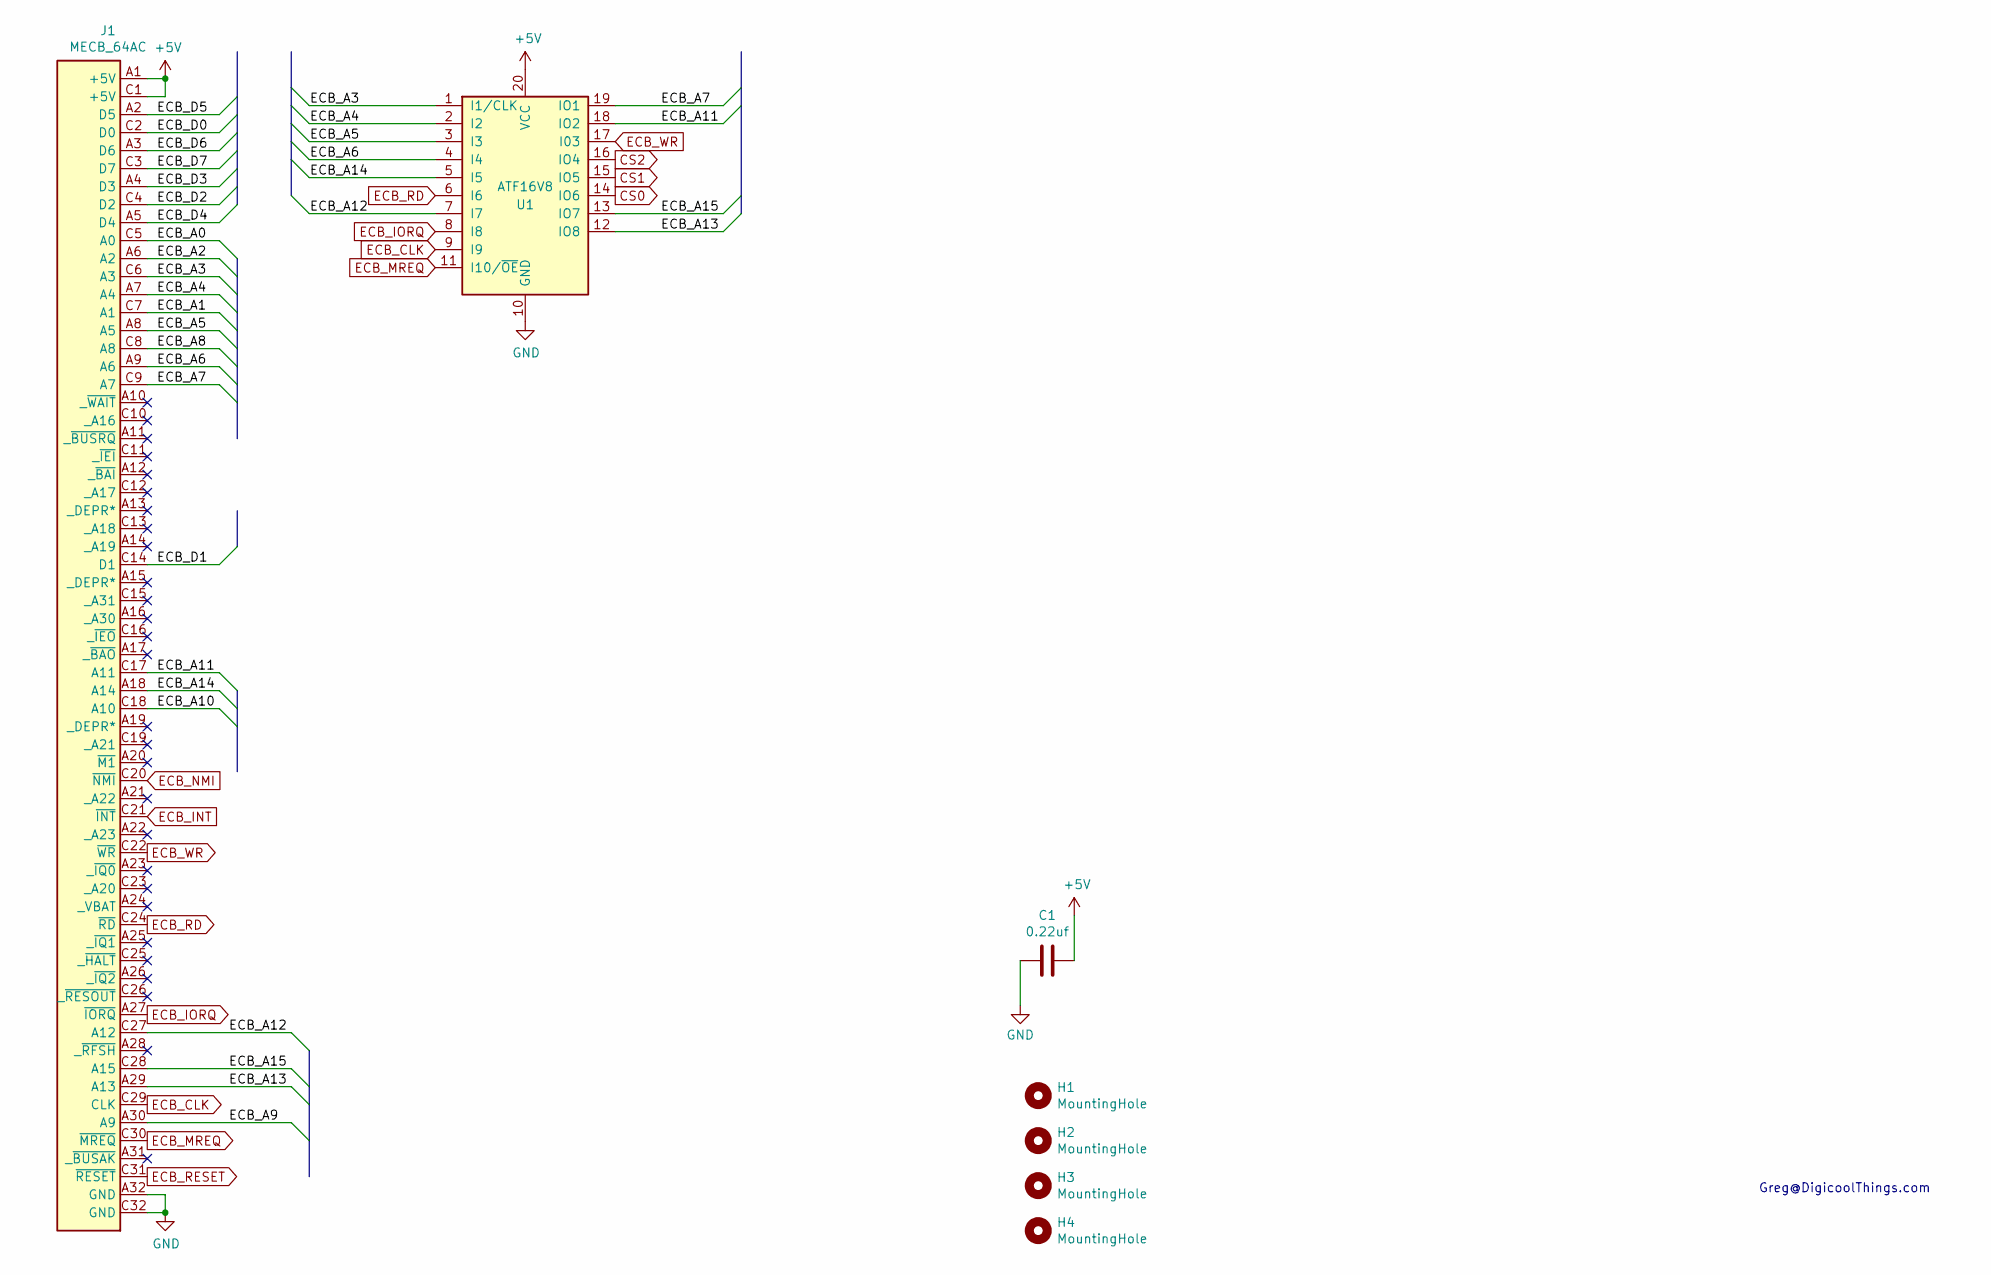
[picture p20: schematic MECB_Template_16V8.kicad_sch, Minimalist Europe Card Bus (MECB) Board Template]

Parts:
C1: 0.22uf; C_Disc_D5.0mm_W2.5mm_P5.00mm
H1, H2, H3, H4: MountingHole; MountingHole_3.2mm_M3
J1: MECB_64AC; DIN41612_C_2x32_C64AC_Male_Horizontal_THT
U1: ATF16V8; DIP-20_W7.62mm_Socket_LongPads_ZIF_friendly

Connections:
+5V: C1.1, J1.A1 (+5V), J1.C1 (+5V), U1.20 (VCC)
/ECB_A0: J1.C5 (A0)
/ECB_A1: J1.C7 (A1)
/ECB_A2: J1.A6 (A2)
/ECB_A3: J1.C6 (A3), U1.1 (I1/CLK)
/ECB_A4: J1.A7 (A4), U1.2 (I2)
/ECB_A5: J1.A8 (A5), U1.3 (I3)
/ECB_A6: J1.A9 (A6), U1.4 (I4)
/ECB_A7: J1.C9 (A7), U1.19 (IO1)
/ECB_A8: J1.C8 (A8)
/ECB_A9: J1.A30 (A9)
/ECB_A10: J1.C18 (A10)
/ECB_A11: J1.C17 (A11), U1.18 (IO2)
/ECB_A12: J1.C27 (A12), U1.7 (I7)
/ECB_A13: J1.A29 (A13), U1.12 (IO8)
/ECB_A14: J1.A18 (A14), U1.5 (I5)
/ECB_A15: J1.C28 (A15), U1.13 (IO7)
/ECB_D0: J1.C2 (D0)
/ECB_D1: J1.C14 (D1)
/ECB_D2: J1.C4 (D2)
/ECB_D3: J1.A4 (D3)
/ECB_D4: J1.A5 (D4)
/ECB_D5: J1.A2 (D5)
/ECB_D6: J1.A3 (D6)
/ECB_D7: J1.C3 (D7)
CS0: U1.14 (IO6)
CS1: U1.15 (IO5)
CS2: U1.16 (IO4)
ECB_CLK: J1.C29 (CLK), U1.9 (I9)
ECB_INT: J1.C21 (~INT)
ECB_IORQ: J1.A27 (~IORQ), U1.8 (I8)
ECB_MREQ: J1.C30 (~MREQ), U1.11 (I10/~OE)
ECB_NMI: J1.C20 (~NMI)
ECB_RD: J1.C24 (~RD), U1.6 (I6)
ECB_RESET: J1.C31 (~RESET)
ECB_WR: J1.C22 (~WR), U1.17 (I03)
GND: C1.2, J1.A32 (GND), J1.C32 (GND), U1.10 (GND)

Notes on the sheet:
Greg@DigicoolThings.com

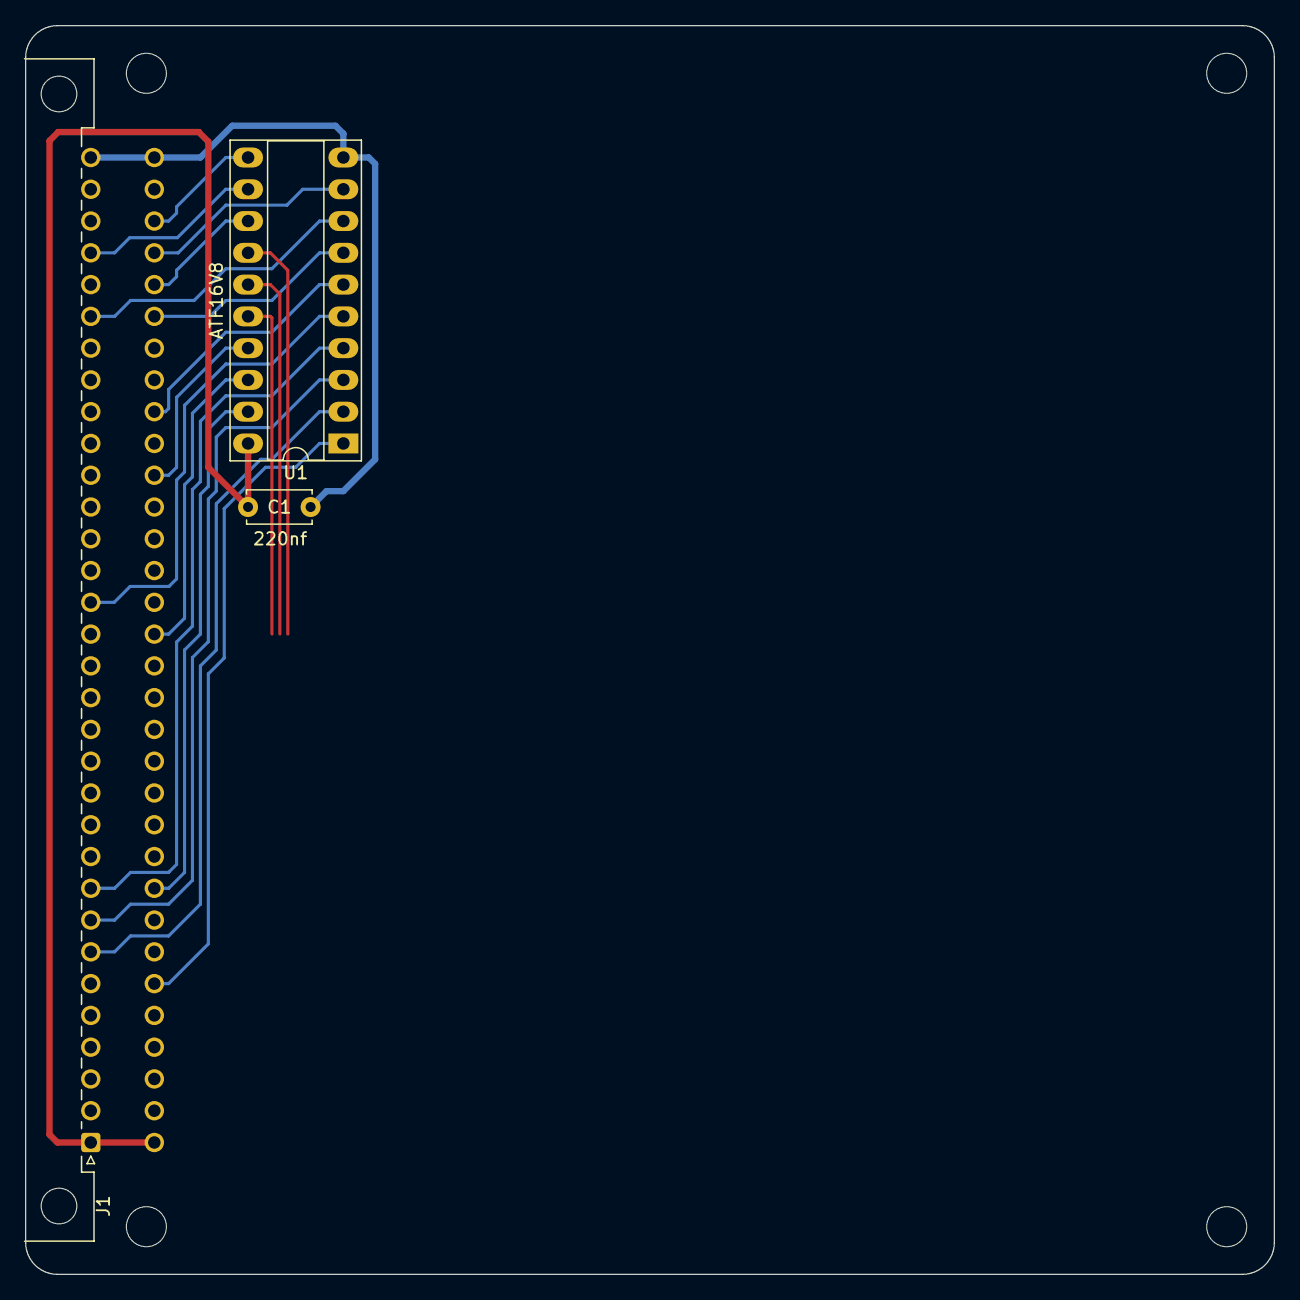
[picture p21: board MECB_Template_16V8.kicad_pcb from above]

Board: 2 copper layers, 99.8 x 99.8 mm, 7 parts (0 on the bottom side), 17 nets.

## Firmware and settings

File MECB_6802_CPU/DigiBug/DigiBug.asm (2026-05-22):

;   DigiBug - for MECB 6802 CPU Card
;   ================================
;
;   Based on Ed Smith's SmithBug code and Mike Lee's updates / corrections.
;
;   Amended for assembly with the ASL Assembler, including various updates.
;   Also, significant addition of comments (as I work through the code) and
;   updated for various bug fixes and adding other corrections & improvements.
;
;   Renamed to DigiBug as the Routine Call Addresses differ from MIKBUG / SmithBug.
;   i.e. Retaining the SmithBug name would imply that SmithBug compatible
;    pre-assembled code would work (which it won't, as call address have changed).
;   To resolve this, DigiBug instead implements a new fixed location Jump Table.
;
;   SmithBug / DigiBug prompt is '> '
;
;   Summary of available Commands:
;       A	Change A pseudoregister and display pseudoregisters 
;       B	Change B pseudoregister and display pseudoregisters 
;       C	Change condition codes pseudoregister and display 
;       	pseudoregisters 
;       D	Disassemble code in memory 
;       E	Examine (or examine and change) a memory location 
;       F	Find a specified byte in a memory block 
;       G	Go to location in PC pseudoregister and execute 
;       H   Help (display Command list)
;       I	Insert a specified value in all locations of a memory 
;       	block  
;       J	Jump to address to be specified 
;       K	Continue with trace at pseudoregister program
;       	counter location 
;       L   Load (S1/S9 format)
;       M	Move a block of memory 
;       N	Inhibit echo to system terminal 
;       O	Allow echo to system terminal 
;       R	Display pseudoregisters (user's stack) 
;       S	Change pseudoregister stack address and display resulting 
;       	pseudoregisters 
;       T	Trace (execute) a program one instruction at a time 
;       V	View a 128-byte block of memory 
;       X	Change X pseudoregister and display pseudoregisters 
;       @	Insert ASCII characters from keyboard 
;       *   Jump to Start (Reset vector)
;
;   Commands that are currently non-operation (to be investigated)
;       1	Set one breakpoint in program and execute beginning at 
;       	pseudoregister program counter location 
;       2	Set two breakpoints and execute as above 
;
;
        CPU     6800        ; Specify MC6800 processor code (asl Assembler)
;
        ORG     $DF00       ; Start of RAM workspace
;
IOV     RMB     2           ; IRQ Interrupt vector
BEGA    RMB     2           ; Entered Begin Address (Start)
ENDA    RMB     2           ; Entered End Address (Thru)
NIO     RMB     2           ; NMI Interrupt vector (initially set to SWI vector)
SP      RMB 2
ACIAT   RMB     1           ; ACIA control register setting
ECHO    RMB     1           ; Echo On = non-zero Flag
ADDRHI  RMB     1           ; Temporary Address (Hi)
ADDRLO  RMB     1           ; Temporary Address (Lo)
TEMP    RMB 1
TW      RMB 2
TFLAG   RMB 1
XTEMP   RMB     2           ; Temporary X register (for 16 bit addition)
BKFLG   RMB 1
SWIPTR  RMB     45          ; SWI Interrupt vector
STACK   RMB     8           ; STACK allocated 8 bytes for SP+7 initial R values
PRINTR  RMB 3
BFLAG   RMB 1
MFLAG   RMB 1
XFLAG   RMB 1
BITE2   RMB 1
BITE3   RMB 15
TSTACK  RMB 2
OPSAVE  RMB 1
PB1     RMB 1
PB2     RMB 1
PB3     RMB 1
BYTECT  RMB 1
PC1     RMB 1
PC2     RMB 1
BPOINT  RMB 3
BKFLG2  RMB 1
MCONT   RMB 1
RECTYP  RMB     1           ; S1/S9 Record Type
BYTECNT RMB     1           ; S1/S9 Line byte count
CHKSUM  RMB     1           ; S1/S9 calculated checksum
;
; ACIA address for MECB 6802 CPU (56K/8K/E0 Memory Map)
; 
ACIACS  EQU     $E008       ; ACIA control/status (Motorola IO Card)
ACIADA  EQU     ACIACS+1    ; ACIA data
;
EOT     EQU     $04         ; EOT control character
BS      EQU     $08         ; BS (Backspace) control character
SPC     EQU     $20         ; Space character   
;
; ROM Start / IO Page for MECB 6802 CPU (56K/8K/E0 Memory Map)
; 
        ORG     $E000
;
; Build an 8K ROMable image with first 256 bytes unused (overwritten by IO page)
;
; Fill the space up to the start of usable ROM space with $FF
;
        dc.b    [(*+($E100-*))&$E100-*]$FF
;
        ORG     $E100           ; Start of usable ROM space
;
; Fixed Jump Table to standard routines (standardise routine call addresses)
;
_START  JMP     START       ; Cold start / reset - monitor entry point
_CONTRL JMP     CONTRL      ; Warm start - monitor entry point
_OQSTNE	JMP     OQSTNE      ; Output Question Mark "?" and Exit to CONTRL
_INADDR JMP     INADDR      ; Input 4 digit Hex Address (to X & ADDRHI/LO)
_INBYTE	JMP     INBYTE      ; Input 2 digit Hex Byte (to A)
_OUTCH	JMP     OUTEEE      ; Output character (redirect to OUTEEE)
_INCH   JMP     INEEE       ; Input character (Redirect to INEEE)
_OUTSTR	JMP     OUTSTR      ; Output EOT terminated string at X
_OUT2H	JMP     OUT2H       ; Output 2 Hex digits of byte at X (X = X+1)
_OUT4HS	JMP     OUT4HS      ; Output 4 Hex digits and space of 2 bytes at X (X = X+2)
_OUT2HS	JMP     OUT2HS      ; Output 2 Hex digits and space of byte at X (X = X+2)
_OCRLF  JMP     OCRLF       ; Output Carriage Return / Line Feed
;
; Monitor Cold Start (Reset) entry point
;
START   LDS     #STACK      ; Initialise Stack Pointer
        STS     SP
        LDAA    #1          ; Set ECHP flag (non-zero)
        STAA    ECHO        ; ECHO On
        LDX     #SFE        ; Initialise SWI & NMI vectors
        STX     SWIPTR
        STX     NIO
;
; ACIA Initialise
;
        LDAA    #$03        ; Reset ACIA
        STAA    ACIACS
        NOP
        NOP
        NOP
        LDAA    #$15        ; /16, 8N1, RTS Low, Interrupt Disabled
        STAA    ACIACS
        STAA    ACIAT       ; Save ACIA Command Register settings
;
; Cold Start Prompt
;
        LDX     #CSPRMPT    ; Display the full Cold Start title
        BSR     OUTSTR
;
; Monitor Warm Start (Command Control)
;
CONTRL  LDAA    ACIAT       ; Restore ACIA to DigiBug setting
        STAA    ACIACS
        LDS     #STACK      ; Reset CONTRL Stack Pointer
        CLR     TFLAG
        CLR     BKFLG
        CLR     BKFLG2
        LDX     #PROMPT     ; Display the prompt
        BSR     OUTSTR
        BSR     INCH        ; Await a command character
        TAB
        JSR     OUTS
;
; Check if Command is Valid and Jump to routine
;
        LDX     #FUTABL     ; Point X at command table
NXTCHR  CMPB    0,X         ; Does entry = B (command)
        BEQ     GOODCH      ; Yes, jump to routine
        INX                 ; No, skip to next command
        INX                 ;
        INX                 ;
        CPX     #TBLEND     ; Are we at the end of the table?
        BNE     NXTCHR      ; No, check next command
        JMP     CKCBA ;
;
GOODCH  LDX     1,X
        JMP     0,X         ; Jump to command routine
;
; IRQ Interrupt Vector Redirect
;
IO      LDX     IOV
        JMP     0,X
;
; NMI Interrupt Vector Redirect
;
POWDWN  LDX     NIO
        JMP     0,X
;
; SWI Interrupt Vector Redirect
;
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

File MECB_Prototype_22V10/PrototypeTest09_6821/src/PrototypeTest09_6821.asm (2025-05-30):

;******************************************************************************
;	PrototypeTest09_6821.asm
;
;	A simple Prototype Card Test (for a 6809 CPU Card).
;
;	Assumes that a 6821 PIA has been connected to the Prototype Card.
;	Uses PORTA to output an incrementing count.
;	
;	Set Entry EQU for your preferred code assembly location.
;	e.g. $0100 specified for running the code in the 2nd page of main RAM.
;	Set PIA EQU for your PIA's base address.
;	e.g. $C0E0 is for $C0 IORQ bank and $E0 I/O allocation. 
;
;	Author: Greg
;	Date:	May 2025
;
;******************************************************************************
Entry		EQU	$0100
PIA		EQU	$C0E0		; MC6821 PIA base address
PIA_PRTA	EQU	PIA		; MC6821 PIA Port A & DDR A address
PIA_CTLA	EQU	PIA+1		; MC6821 PIA Control Register A address
;
; Code Entry Point
		ORG	Entry
; Initialise PIA
		CLRA
		STA	PIA_CTLA	; Initilise PIA Control, Select DDRA
		LDA	#$FF		
		STA	PIA_PRTA	; PORTA as outputs (DDR = 1)
		LDA	#$04		
		STA	PIA_CTLA	; Now select PORTA Data Register
;
		CLRA			; Initialize Accumulator A to zero
CNTLOOP		STA	PIA_PRTA	; Output Accumulator A to PORTA
		LDX	#$FFFF		; Ultra simple delay loop!
DELAY		LEAX	-1,X		; Decrement X
		BNE	DELAY		; If not yet zero, then loop
		INCA			; Increment Accumulator A counter
		BRA	CNTLOOP		; Branch forever in our counter loop!
;
		END

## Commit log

2022-03-01 Update README.md
    Add MECB Board Mechanical image.
2022-03-02 Initial commit of KiCAD v6 MECB_Template folder, Board Mechanical Specification PDF, and associated README updates.
    [MECB_Template.kicad_pcb, MECB_Template.kicad_sch]
2023-01-15 Initial commit of 6809 CPU card & TMS992xA VDP card WinCupl PAL source and 6809 initial test assembly source
2023-01-16 Redefined to now assign active low signals at the pin declaration, so all logic definitions are now consistently positive logic assertions (therefore easier to read and avoid inverse logic errors).
2023-07-17 Update MECB_Template files to KiCAD v7
    [MECB_Template.kicad_pcb, MECB_Template.kicad_sch]
2023-07-17 Update README.md for KiCAD v7 reference.
2023-07-17 Add KiCAD Gerbers and Project files for currently completed MECB Cards. i.e. MECB_Backplane, MECB_Prototype, and MECB_TMS992xA_VDP Cards.
    [MECB_BackPlane.kicad_pcb, MECB_BackPlane.kicad_sch, MECB_Prototype.kicad_pcb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]
2023-07-17 Normalise folder card structure and inclusion of Gerbers and PDF viewable Schematics.
    [MECB_BackPlane.kicad_pcb, MECB_BackPlane.kicad_sch, MECB_Prototype.kicad_pcb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]
2023-07-20 Add Assembled board images. Add correct schematic for MECB_BackPlane.
2023-10-01 Add assembly source for the RAM version of InitialTest09, and the three Christmas09 VDP and Sound test demos.
2023-10-28 Various board resource additions,6809 source and ROM images.
2023-11-12 Add 6809 CPU Card BOM PDF
2024-03-22 Add MECB 1MB ROM Expansion Card folder and gerbers etc. Update 6809 CPU Card PLD Source for additional Memory Map options. Add ASSIST09 original Source Code made compatible with ASM6809 Assembler. Ad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
2024-05-11 Minor update to v2.4. Due to an oversight, v2.3 inadvertantly included a double-up ROM_WR pull-up resistor. This doesn't cause any isues, so v2.4 is just a tidy-up, which also allowed returning to se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
2024-06-07 Add MECB_6502_CPU_Card. Also a small correction to 6809 CPU Card BOM (remove surplus 74HCT244 line).
2024-06-15 Added HD63C09_PLCC-DIP40_Adapter Gerbers and Schematic PDF to MECB_6809_CPU project
2024-07-13 Update KiCAD Template files for KiCAD v8 (no functional change).
    [MECB_Template.kicad_pcb, MECB_Template.kicad_sch]
2024-07-13 Update MECB_6502_CPU for v1.2 - Minor version change for update of PLD (U1) & ROM (U4) footprints to be ZIF socket friendly (1.0mm pad holes, instead of 0.8mm).
2024-07-14 Update MECB_6809_CPU to v2.5 - Minor version change for update of PLD (U1) & ROM (U4) footprints to be ZIF socket friendly (1.0mm pad holes, instead of 0.8mm).
2024-07-21 Update WinCUPL source files for 6502_CPU / Motorola_IO / TMS992x_VDP for CreatiVision re-Creation (commented out).
2024-08-29 Minor MECB_6502_CPU update to silkscreens (non-functional changes). Updated BOM for v1.3. Added v1.3 Assembled board photo.
2024-10-26 Add MECB_Backplane_Extension v1.0 - PLEASE NOTE: This is currently untested. Use gerbers at your own risk!
2025-02-20 MECB_Motorola_IO v1.2 update - Trivial update to change Audio Out header from 2-pin to 3-pin, for consistency with other new MECB Cards with Audio Out headers. Also adding Schematic PDFs and PCB rend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
2025-04-17 Updated MECB_6809_CPU assembled photos clarifying 56K/8K and 48K/16K memory maps and DIP switch settings.
2025-05-04 Add new KiCAD Template for 22V10 PLD, and update prior 16V8 PLD template for KiCAD v9.0.1. The two new named templates, replace the prior sinfle template (16V8 based).
    [MECB_Template.kicad_pcb, MECB_Template_16V8.kicad_pcb, MECB_Template_16V8.kicad_sch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]
2025-05-04 Update README.md for new KiCAD Templates
2025-05-08 Add Programmers Guide and 6809 Assembly TEXT mode test source code, to MECB_TMS9918_or_TMS992x_VDP
2025-05-08 Fixing a naming case-sensitive issue.
2025-05-08 Renaming of WinCUPL files to clarify 16V8 vs 22V10 device selection.
2025-05-08 Renaming of WinCUPL files to clarify 16V8 vs 22V10 device selection (naming case consistancy adjustments).
2025-05-30 Add MECB_Prototype_22V10 folder and resources. Add MECB_Prototype_16V8 BOM. Rename .jed file (for naming consistancy).
2025-11-14 Add CHIPOS ROM images to MECB_6809_CPU and MECB_6309_CPU_PLCC folders. Note: These ROM images require additional system boards as per the DREAM 6800 (6809) re-Creation project.
2026-01-16 Added BOM (.pdf & .png) for MECB_Motorola_IO
2026-01-16 MECB_Motorola_IO - Minor update to Gerbers (silkscreen only). Updated PCB 3D Renders. Rename Schematic (current / no version number).
2026-01-17 MECB_Motorola_IO - Minor clarification on BOM item description.
2026-02-17 MECB_68008_CPU - Update BOM
2026-02-25 MECB_68008_CPU - Add Xmas_OLED demo / test. Add Motorola Educational Computer Board User Manual (MecbManual.pdf).
2026-04-06 Update MECB KiCAD Templates. Include 220nf bypass capacitor. Re-route tracks based on new capacitor positioning. Update 3D images to be new blue colouring. Correct earth zone inner corner rounding.
    [MECB_Template_16V8.kicad_pcb, MECB_Template_16V8.kicad_sch, MECB_Template_22V10.kicad_pcb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]
2026-04-19 MECB_OLED_Display_128x64 - Added OLED_128x64_Test.S19 and OLED_128x64_Test.lst files, to enable quick testing without needing to first assemble the .asm source code file.
2026-08-23 MECB_Prototype_16V8 - Update Schematic, BOM, and Gerbers for 220nf PLD bypass capacitor. Add PCB 3D render.
2026-08-23 MECB_Prototype_16V8 - correct transperancy in PCB 3D render png image.
2026-09-08 MECB_Template_16V8 - Update to KiCAD v10.0. Add missing MECB footprint library folder.
    [MECB_Template_16V8.kicad_pcb, MECB_Template_16V8.kicad_sch]
2026-09-08 MECB_Template_22V10 - Update to KiCAD v10.0. Add missing MECB footprint library folder.
    [MECB_Template_22V10.kicad_pcb, MECB_Template_22V10.kicad_sch]
2026-09-16 MECB_68008_CPU v2.0 - Update silkscreen for 220nf PLD Bypass and C2-C7 positions (alongside U2 - U7). No version number change as aesthetic change only.
2026-11-10 MECB_OLED_Display_128x64 - Minor BOM update (wording only).
2026-11-10 MECB_Backplane - Minor BOM update (wording only).
